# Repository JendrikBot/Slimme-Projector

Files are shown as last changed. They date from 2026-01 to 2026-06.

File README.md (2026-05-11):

# slimme lichtprojector
de slimme lichtprojector die kinderen ondersteunt bij het krijgen van een goede nachtrust.

🛠️ Built by Felix Vanhoutte & Jendrik Bottelberghe   
🔥 Supervised by prof. dr. Bas Baccarne& Yannick Christiaens. 
🌱 Grown at Ghent University 🏛️ Industrial Design Engineering ([project overview](https://github.com/basbaccarne/human-centered-design))       

11/05/2026 van de laatste update  

## Samenvatting
Slaapregressie bij jonge kinderen tussen 1,5 en 2,5 jaar vormt een terugkerend probleem voor gezinnen. Kinderen worden ’s nachts herhaaldelijk wakker en zoeken nabijheid en emotionele geruststelling, terwijl ouders te maken krijgen met slaaptekort, onzekerheid en een verhoogde mentale belasting. Bestaande oplossingen sluiten onvoldoende aan bij deze leeftijdsfase en vereisen vaak actieve ouderlijke tussenkomst of zorgen voor extra prikkels.

Het probleem werd onderzocht via gebruikersonderzoek en benchmarkanalyse. Er werden drie semigestructureerde interviews afgenomen met ouders en een grootouder die ervaring hebben met slaapregressie. De interviews focusten op nachtelijke patronen, emotionele impact en het gebruik van bestaande hulpmiddelen en werden geanalyseerd via thematische analyse. Daarnaast werd een benchmark uitgevoerd van tien bestaande producten en diensten rond slaapondersteuning bij jonge kinderen.

Op basis van deze inzichten werd een warm, slaapondersteunend systeem voorgesteld dat inspeelt op emotionele regulatie in plaats van gedragssturing. De oplossing maakt gebruik van subtiele zintuiglijke signalen zoals zacht licht, geluid en ritme, zonder schermen of actieve interactie.

Door automatisch en passief te werken, biedt het systeem het kind een gevoel van nabijheid en veiligheid, terwijl de nood aan nachtelijke ouderlijke tussenkomst vermindert. Zo creëert de oplossing rust voor zowel kind als ouder.

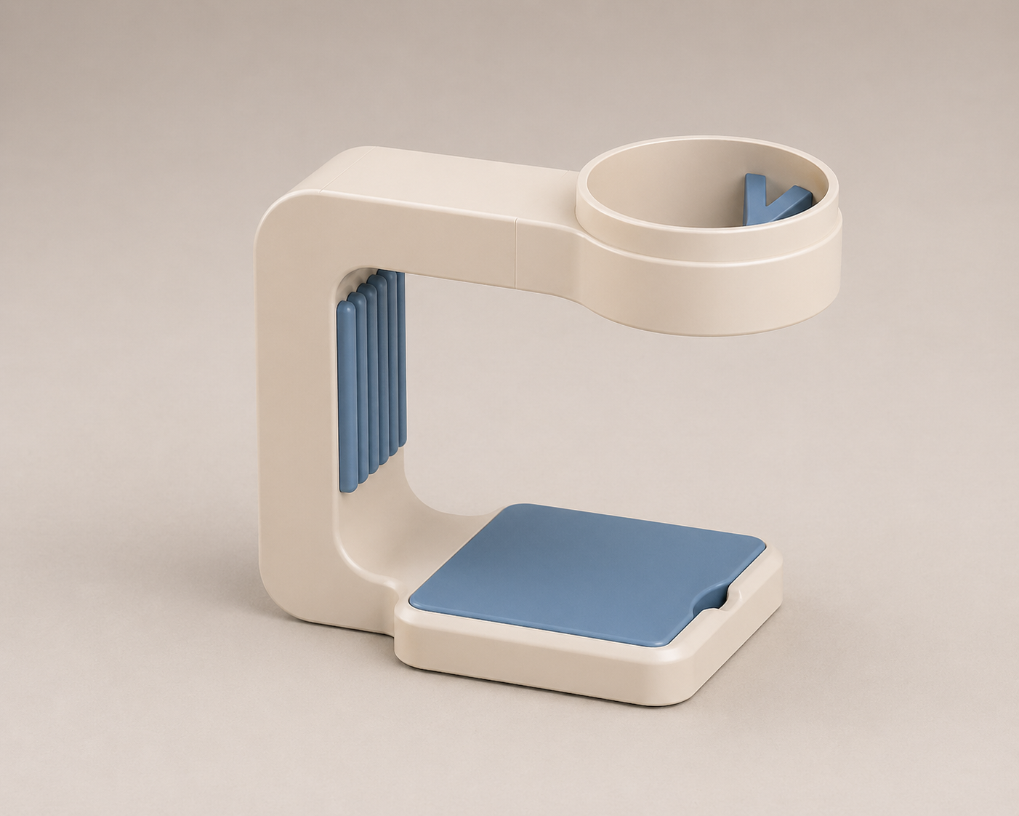
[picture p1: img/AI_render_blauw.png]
render


## Introductie
De slimme lichtprojector biedt hulp aan kinderen met slaapproblematiek. Het probleem dat ouders midden in de nacht wakker gemaakt worden door hun kinderen dient opgelost te worden met behulp van ons project. De slimme lichtprojector merkt op dat het kind ontwaakt en schiet meteen in actie. De projector schijnt rustgevende, ritmische beelden of strobes en maakt witte ruis om het kind rustiger te maken. De instellingen van de projector kunnen door de ouders ingesteld worden met behulp van een app. Zo kan het product op elk kind afgesteld worden. Het is de bedoeling dat de projector zo gemakkelijk mogelijk te installeren is, zonder veel kabels te moeten verbinden of gaten te moeten boren in het plafond. 

Maak gebruik van bronverwijzingen ([zie APA stijl](https://www.scribbr.nl/category/apa-stijl/)). Zoals bijvoorbeeld (Thomas & Ritter, 2022) [^1] .

## Inhoudstafel

1. [Methodologie](./docs/methodologie.md)
2. [Discovery](./docs/discovery.md)
3. [Definition](./docs/definition.md)
4. [Develop](./docs/develop.md)
5. [Design Requirements](./docs/design_requirements.md)
6. [Bill of materials](./docs/bom.md)

## Kritische reflectie

We hebben in deze fase van het ontwerpproces al verschillende waardevolle inzichten verkregen die richting geven aan belangrijke ontwerpkeuzes. Zowel uit de discovery-fase als uit de daaropvolgende gebruikerstesten werd duidelijk welke elementen essentieel zijn voor een effectief en rustgevend slaapondersteunend systeem. Zo bevestigden de interviews en benchmarkstudie dat slaapregressie bij jonge kinderen primair een probleem is van emotionele regulatie en nabijheidsbehoefte, en dat bestaande oplossingen onvoldoende aansluiten bij deze specifieke leeftijdsgroep. De gebruikerstesten met het ophangsysteem, de spreekfunctie en de energievoorziening brachten bovendien concrete frictiepunten aan het licht rond veiligheid, installatiegemak, voorspelbaarheid en betrouwbaarheid in een nachtelijke context.

Tegelijkertijd zijn er nog verschillende elementen waarin we ons verder willen verdiepen. Zo blijft de vraag open hoe het ophangsysteem even veilig en stabiel kan worden ontworpen zonder invasieve installatie zoals boren, en hoe dit op een intuïtieve manier kan worden gecommuniceerd naar ouders. Ook de automatische en passieve activatie van de spreekfunctie tijdens de nacht vraagt verdere uitwerking, zowel technisch als in termen van gebruikservaring en controle. Daarnaast is het nodig om de voorspelbaarheid van het systeemgedrag verder te versterken, zodat zowel kind als ouder vertrouwen kunnen opbouwen in de werking ervan. Deze open vragen vormen duidelijke ontwerpopportuniteiten voor de volgende iteraties.

We zijn tevreden over de manier waarop het onderzoek tot nu toe werd opgezet en uitgevoerd. De combinatie van semigestructureerde interviews, benchmarkanalyse en taakgebaseerde gebruikerstesten leverde rijke, relevante inzichten op die rechtstreeks konden worden vertaald naar design requirements en ontwerpimplicaties. Ook de keuze om te werken met low-fidelity prototypes en Figma-simulaties bleek effectief om vroegtijdig gebruikservaringen te testen zonder onnodige technische complexiteit.

Het teamwork had in deze fase beter kunnen verlopen. Er waren momenten waarop de afstemming en taakverdeling niet optimaal waren, wat soms leidde tot vertragingen of onduidelijkheden. Dit werd echter onderling besproken en geëvalueerd, en er zijn duidelijke afspraken gemaakt om de samenwerking in de volgende fases gestructureerder en efficiënter aan te pakken. Er wordt rekening gehouden met een betere planning, helderdere communicatie en een evenwichtige verdeling van verantwoordelijkheden. Hierdoor verwachten we dat ons team in de volgende ontwerpfases doelgerichter en coherenter kan werken aan de verdere ontwikkeling van het concept.

## Noot inzake het gebruik van AI
AI werd in dit project gebruikt om duiding te geven bij opdrachten, het helpen opstellen van de protocols met eigen bijsturing, en het herschrijven en grammatisch corrigeren van bepaalde stukken tekst. Artificiële intilligentie werd niet gebruikt als bron, echter biedde het wel hulp bij het uitleggen en sturen van onderzoek.

## Bijlagen
### Discovery

* Literatuuronderzoek (N=)
  * [Protocol](./reports%20and%20protocols/Bottelberghe_Jendrik_Protocol%20literatuuronderzoek%20JB.pdf)
  * [Rapport](./reports%20and%20protocols/Bottelberghe_Jendrik_rapportering%20literatuuronderzoek%20JB.pdf)
* Interviews (N=6)
  * [Protocol_1](./reports%20and%20protocols/Bottelberghe_Jendrik_Interview_protocol_PGGO_dokter%20JB.pdf)
  * [protocol_2](./reports%20and%20protocols/Bottelberghe_Jendrik_Interview_protocol_PGGO_ouders%20JB.pdf)
  * [Rapport](./reports%20and%20protocols/Bottelberghe_Jendrik_Rapportering%20interviews%20JB.pdf)

### Definition
* User testing wave 1 (N=8)
  * [Protocol](./reports%20and%20protocols/Bottelberghe_Jendrik_onderzoeksprotocol%20ophangsysteem.pdf)
  * [Rapport](./reports%20and%20protocols/Bottelberghe_Jendrik_rapportering%20TAP.pdf)
* User testing wave 2 (N=8)
  * [Protocol](url)
  * [Rapport](url)

* Literatuuronderzoek 
  * [Protocol](./reports%20and%20protocols/Bottelberghe_Jendrik_Protocol%20literatuuronderzoek%20JB.pdf)
  * [Rapport](./reports%20and%20protocols/Bottelberghe_Jendrik_rapportering%20literatuuronderzoek%20JB.pdf)
* Benchmarkonderzoek
  * [protocol](./reports%20and%20protocols/Benchmarkprotocol_slaapregressie%20Felix.pdf)
  * [rapport](./reports%20and%20protocols/Benchmark_uitvoering_slaapregressieFelix.pdf)
* Interviews (N=6)
  * [Protocol_Jendrik_1](./reports%20and%20protocols/Bottelberghe_Jendrik_Interview_protocol_PGGO_dokter%20JB.pdf)
  * [protocol_Jendrik_2](./reports%20and%20protocols/Bottelberghe_Jendrik_Interview_protocol_PGGO_ouders%20JB.pdf)
  * [protocol_Felix](./reports%20and%20protocols/Interview%20-%20protocol%20Felix.pdf)
  * [Rapport_Jendrik](./reports%20and%20protocols/Bottelberghe_Jendrik_Rapportering%20interviews%20JB.pdf)
  * [rapport_Felix](./reports%20and%20protocols/Interview%20report%20Felix.pdf)
### Definition
* User testing wave 1 (N=4)
  * [Protocol_Jendrik](./reports%20and%20protocols/Bottelberghe_Jendrik_onderzoeksprotocol%20ophangsysteem.pdf)
  * [Rapport_Jendrik](./reports%20and%20protocols/Bottelberghe_Jendrik_rapportering%20TAP.pdf)
* User testing wave 2 (N=4)
  * [Protocol_Felix](./reports%20and%20protocols/Onderzoeksprotocol%20spreekfunctie,%20energievoorziening%20(QAP).pdf)
  * [Rapport_Felix](./reports%20and%20protocols/FelixVanhoutteRapporteringQAP.pdf)

## Licentie

This repository contains both software and design materials created as part of an industrial design engineering project at Ghent University.

- **Software and code:** [MIT License](./LICENSE-MIT)  
- **Design, documentation, CAD, and media:** [CC BY 4.0 License](./LICENSE)
  
You are free to reuse and build upon this work, both commercially and non-commercially, as long as proper attribution is given to the original authors.

## Bronnen
Summer, J. V. (2025, 11 juli). What color light helps you sleep? Sleep Foundation. https://www.sleepfoundation.org/bedroom-environment/what-color-light-helps-you-sleep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,morning%2C%20known%20as%20sleep%20inertia

Sleep Foundation. (2025, 29 juli). Music and Sleep. https://www.sleepfoundation.org/noise-and-sleep/music

Loewy, J. L. (2013). The Effects of Music Therapy on Vital Signs, Feeding, and Sleep in Premature Infants (5de editie, Vol. 131). https://publications.aap.org/pediatrics/article-abstract/131/5/902/31313/The-Effects-of-Music-Therapy-on-Vital-Signs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

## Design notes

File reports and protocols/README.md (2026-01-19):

Add PDF versions of your protocols and reports here.   
   
- ❗Make sure this data is pseudonomized (give an alias to your respondent)    
- ❗Don't share personal information here.   
- ❗For informed consents and other documents that contain personal information: Add links to a OndeDrive folder and only give access to teachers.

## Reports

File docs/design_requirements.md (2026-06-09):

## Overzicht van Design Requirements

| ID | Beschrijving | Bron | Status |
|----|---|---|---|
| **1.1** | Het systeem moet emotionele geruststelling bieden aan kinderen via zachte, niet-stimulerende signalen (licht, geluid, ritme). | Discovery – Interviews, Thema 2 | ✅ voldaan |
| **1.2** | Het systeem mag geen overprikkeling veroorzaken (geen schermen, felle kleuren, harde geluiden of complexe interacties). | Discovery – Benchmark, Thema 4 | ✅ voldaan |
| **1.3** | Het systeem moet autonoom en passief kunnen functioneren tijdens de nacht, zonder actieve tussenkomst van ouders. | Discovery – Designimplicaties | ✅ voldaan |
| **1.4** | Het systeem moet voorspelbaar en consistent gedrag vertonen zodat kind en ouder conditionering en vertrouwen kunnen opbouwen. | Discovery – Thema 1 | ✅ voldaan |
| **2.1** | Het systeem moet altijd beschikbaar en betrouwbaar zijn gedurende de volledige nacht. | Definition – Energievoorzieningstest (QAP) | ✅ voldaan |
~~| **2.2** | De spreekfunctie moet onmiddellijk herkenbaar zijn als een geruststellende ouderstem en geen extra mentale belasting veroorzaken. | User test – QAP | ⚠️ gedeeltelijk voldaan |~~
| **2.3** | Het ophangsysteem moet veilig, stabiel en niet-storend zijn in de slaapkamercontext. | User test – Wave 2 | ✅ voldaan |
| **2.4** | De installatie van het systeem moet laagdrempelig en intuïtief zijn, met minimale invasiviteit (bijv. zonder boren). | User test – Think Aloud / Wave 2 | ✅ voldaan |
| **3.1** | Het systeem moet huilgeluiden van een kind kunnen detecteren op basis van een instelbare geluidsdrempel zodat vals alarm door achtergrondgeluid wordt vermeden. | Develop – Detectiedrempel (Decibel) | ✅ voldaan |
| **3.2** | Het systeem moet automatisch een rustgevende projectie activeren wanneer huilen wordt gedetecteerd zonder dat ouders moeten ingrijpen.  | Develop – User flow / Activatie | ✅ voldaan |
| **3.3** | Het systeem moet binnen enkele seconden reageren nadat een relevant huilgeluid is gedetecteerd. | Develop – Reactiesnelheid systeem | ✅ voldaan |
| **3.4** | Het systeem moet automatisch terugkeren naar monitoringmodus wanneer het huilen stopt. | Develop – User flow | ✅ voldaan |
| **3.5** | Het systeem moet binnen ≤ 3 seconden operationeel zijn na activatie. | Develop – User test | ✅ voldaan |
| **3.6** | De powerknop moet direct zichtbaar en herkenbaar zijn (visuele signifier). | Develop – User test | ❌ niet voldaan |
| **3.7** | Het geluidsniveau moet onder een storingsdrempel liggen voor nachtgebruik. | Develop – User test | ⚠️ gedeeltelijk voldaan |

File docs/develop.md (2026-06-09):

## Develop

## Develop 1

## Analyse en Prioritering

1. Onderzoeksvragen + hypotheses

1.1. Effectiviteit van het systeem

· Hoe effectief is het systeem in het detecteren en reageren op geluid?

· Het systeem reageert correct op relevante geluiden en vermindert het probleem waarvoor het ontworpen is.

1.2. Detectiedrempel (Decibel)

· Vanaf welk geluidsniveau moet het systeem reageren om vals alarm te vermijden?

· Een drempel boven het gemiddelde achtergrondgeluid zorgt ervoor dat het systeem enkel reageert op relevante geluiden. Later is het eventueel ook mogelijk om een algoritme te gebruiken dat kinder- en volwassengeluiden onderscheidt.

1.3. Integratie van een speaker

· Verhoogt een geïntegreerde speaker de effectiviteit van het systeem?

· Het rustegevende effect van geluid kan niet gegarandeerd worden en wordt dus niet verde meegenomen. verder zou een auditieve uitvoer voor een audio feedback loop kunnen zorgen.

1.4. Installatie / ophangen

· Is het haalbaar en praktisch om het systeem op te hangen?

· Het vermoeden is dat het systeem beter zal werken als het op een nachtkastje of op de grond zal staan. Ook is het dan makkelijker te installeren.

1.5. Reactiesnelheid van het systeem

· Hoe snel moet het systeem reageren nadat een relevant geluid is gedetecteerd?

· Het systeem moet binnen enkele seconden reageren na detectie van een relevant geluid om effectief te zijn en de gewenste reactie uit te lokken

## Deconstructie

**storyboard**

Om een duidelijker beeld te krijgen in de visie van de werking van het systeem werd een nieuwe iteratie van een storyboard gemaakt. Dit werd getekend, rekening houdend met de inzchten die verkregen werden tijdens de feedback. Na overleg van de priotering werd dit [storyboard](/img/afbeelding%20storyboard%20develop%201.JPEG) getekend.

**Productarchitectuur (I/O)**

Om vroegtijdig een beeld te krijgen van naarmate de technische ideeën mogelijk waren, werd een raspberry pi zero 2 W aangekocht samen met een draagbare projector. Toen de verbinding met behulp van code slaagde, was het duidelijk dat er op deze manier verder gebouwd kon worden. De verschillende sensoren, actuatoren en datastromen  zijn in een [productarchitectuur](/img/productarchitectuur_develop_1.png) in kaart gebracht.

**User flows & Informatiearchitectuur**

* User flow
Deze [user flow](/img/userflow_develop_1.jpg) is gebaseerd op de Hierarchical Task Analysis (HTA) met als hoofddoel “0. Het kind terug in slaap krijgen”. Wanneer het kind begint te huilen, detecteert de microfoon van het systeem het geluid en analyseert het of het effectief om huilen gaat. Indien dit het geval is, activeert het systeem automatisch de projector.

De projector projecteert rustgevende beelden op het plafond. Zodra het huilen stopt en het kind opnieuw rustig wordt, detecteert het systeem dit en dimt de projector geleidelijk. Daarna keert het systeem terug naar de monitoringmodus.

Deze flow toont hoe het systeem automatisch reageert op huilen en het kind helpt om opnieuw in slaap te vallen zonder tussenkomst van de ouders.

* Informatiearchitectuur

1. Information Ecology

Gebruikers:
· Ouders van kinderen die slaapregressie ervaren

· Vermoeide ouders die een snelle en eenvoudige interactie nodig hebben

· Het kind dat indirect met het systeem interageert

Inhoud:
· Detectie van huilen

· Gevoeligheid van de microfoon

· Projector aan/uit

· Type projectie

· Animatie

· Timer

· Automatische activatie

· Slaapstatus van het kind

· Meldingen naar ouders

· Instellingen

Context:
· Gebruik tijdens de nacht

· Ouders hebben weinig aandacht of energie om met het systeem te interageren

· Minimale interactie is gewenst

· Het product reageert automatisch wanneer het kind huilt

1. Card Sorting Methode

Voor het bepalen van de informatiearchitectuur werd een open card sorting methode gebruikt. Deelnemers kregen kaarten met verschillende functies van het systeem en werden gevraagd deze in logische groepen te verdelen. Daarna gaven zij elke groep een naam. Deze methode helpt om de mentale modellen van gebruikers te begrijpen.

| Informatie-item | Detectie | Projector | Geluid | Automatisch systeem | Instellingen |
|---|---|---|---|---|---|
| Microfoon detecteert huilen  | ✓ | | | | |
| Huilanalyse | ✓ | | | | |
| Projector starten | | ✓ | | | |
| Projectie kiezen | | ✓ | | | |
| Helderheid | | ✓ | | | |
| Rustgevende muziek | | | ✓ | | |
| Volume | | | ✓ | | |
| White noise | | | ✓ | | |
| Automatische activatie | | | | ✓ | |
| Timer | | | | ✓ | |
| Nachtmodus | | | | ✓ | |
| Microfoon gevoeligheid | | | | | ✓ |
| Meldingen naar ouders | | | | | ✓ |

 ## Diagram / Informatiearchitectuur

- **Slaapprojector Systeem**
  - **Detectie**
    - Huildetectie via microfoon
    - Geluidsanalyse
    - Slaapstatus kind
  - **Projectie**
    - Projector aan/uit
    - Type projectie
    - Animatie
    - Helderheid
  - **Geluid**
    - Rustgevende deuntjes
    - Muziekselectie
    - White noise
    - Volume
  - **Automatische reactie**
    - Activatie bij huilen
    - Timer
    - Nachtmodus
  - **Instellingen**
    - Microfoongevoeligheid
    - Meldingen naar ouders
    - Systeeminstellingen

**MVP-definitie**

In deze fase werd duidelijk dat de prioriteiten voor een deel anders liggen dan voordien. De focus van dit product lag in het begin van de fases vooral op het dilemma dat ging over het installatiesysteem (ophanging of neerzetten). In deze fase lag dit eerder achterwege. Nu de projector aangekocht is, kan meer gefocust worden op aspecten zoals activatie, geluid detectie en het beperken van mogelijke nadelen.
De minimal viabel productfuncties besluiten we op basis hiervan:

* Wake detection: activatie als drempelwaarde overschreden wordt.

* Activatie van systeem: Python programma draait automatisch na opstarten, zonder manuele interactie.

* Onderdrukking van bijkomende ruis:  Het bijkomend lawaai van de ingebouwde ventilatie in de projector is geen storende factor.

***Een systeem dat automatisch geluid detecteert bij een slapend kind en een rustgevende projectie toont om het kind weer tot rust te brengen.***

## Divergentie & Ontwerpkeuzes

* Morfologische Matrix:

| Functie / Probleem | Oplossing 1 | Oplossing 2 | Oplossing 3 | Oplossing 4 |
|---|---|---|---|---|
| Detectie van huilen / wakker zijn | Microfoon | Bewegingssensor | Combinatie geluid + beweging | |
| Activatie systeem | Automatisch bij huilen | Bij beweging van het kind | Handmatig via app | Constant aan |
| Visuele geruststelling | Sterrenprojectie | Dierenanimaties | Rustgevende kleuren | Bewegende wolken | |
| Intensiteit aanpassen | Vast niveau | Automatisch aanpassen | Manueel instellen via de app | Adaptief op basis van huilvolume |
| Stoppen van projectie | Timer | Wanneer huilen stopt | Ouder via app | Geleidelijke dimmen |
| Feedback naar ouders | Geen feedback | Meldingen via app | Geluidsmelding | Slaaprapport |

* Toelichting:

Om verschillende oplossingsmogelijkheden te verkennen werd een morfologische matrix opgesteld. Deze methode helpt om voor elke functionele uitdaging meerdere mogelijke oplossingen te genereren en te combineren. Hierdoor is het mogelijk om systematisch verschillende ontwerpvarianten te onderzoeken.

Voor het slaapprojector-concept werden onder andere oplossingen onderzocht voor de detectie van huilen, de activatie van het systeem, visuele geruststelling en het automatisch stoppen van het systeem. Door verschillende oplossingen uit de matrix te combineren kunnen meerdere conceptvarianten worden ontwikkeld.

## Build & Test

In deze fase van het ontwerp was het vooral belangrijk om een idee te krijgen in de moeilijkheidsgraad van de werking. Het voornaamste doel was om te kunnen bewijzen dat een audio-input een output kon geven via een projector, en dit is geslaagd. Nu het zeker is dat het mogelijk is om op de huidige componenten verder te bouwen, volgen meer user-tests en gebruikersonderzoeken. De [eerste iteratie](/img/afbeelding_samenstelling_1.JPEG) van de proof of concept bestond uit een custom 3D-print dat de boog van de projector volgt, beschikt met gaten om de raspberry pi module aan te bevestigen. Deze werd met plakband vastgemaakt om een oordeel te kunnen vellen over passing. De [tweede iteratie](/img/afbeelding_samenstelling_2.JPG) kwam na de conclusie dat de passing voldeed en bevestigt de componenten met klitteband.

## Develop 2

**Usability Goals**

Voor dit ontwerp is het voor de gebruiksvriendelijkheid het belangrijkst dat de projector makkelijk en intuïtief op te stellen is. Ook was het belangrijk dat de projector een mooie projectie had, ookal was het makkelijk om op te stellen. Als rode draad door het project speelde de veiligheid van het kind ook een primaire rol.

* De projector kan opgezet worden binnen 120 seconden.

* De projectie is scherp

* Het ontwerp is kindveilig

**Antropometrische analyse**

In dit project leek een Antropometrische analyse eerst weinig zin te hebben, aangezien het ontwerp niet zwaar was en geplaatst wordt op een nachtkast of dergelijke dat afhankelijk is van de gebruiker.
Waar in dit project wel rekening mee gehouden kan worden zijn de minimale en maximale afmetingen voor een scherp beeld. Er werd gezocht naar de kortste en verste afstand tussen projector en projectvlak waarbij het beeld scherp kon zijn en dit bracht volgende resultaten:

| | lengte (mm) | hoogte (mm) | afstand (mm) |
|---|---|---|---|
| min voc | 670 | 375 | 650 |
| max voc | 2050 | – | 1860 |

Uit deze resultaten blijkt dat er weinig tot geen rekening gehouden moet worden met deze parameters. Er kan geconcludeerd worden dat een stationaire projector (staand) zonder problemen gebruikt kan worden. 

**Cognitieve & sensoriële ergonomie**

Na Develop 1 werd een [nieuw prototype]() ontworpen. Hoewel dit een stap in de goede richting was, was dit niet volledig geschikt om mee verder te gaan. Het model was te groot en te omvangrijk om esthetische waarde te hebben. Na vorig ontwerp werd een [tweede iteratie](/img/develop_2_prototype.JPEG) ontworpen, dit keer werd besloten om de kabels minder te verstoppen en verder te werken op de support. Met dit prototype werd een praktijktest uitgevoerd om tekortkomingen na te gaan bij gebruikers. Hoewel het project systemisch wel slaagde, waren er 2 grote werkpunten. Zo was de opstarttijd te lang waardoor de *Gulf of Execution* vergroot, aangezien het ontwakingsmoment niet meteen kan opgevangen worden door een reactie. Het tweede grote werkpunt was het storende geluid van de projector. Uit deze frustraties en de andere interacties die uit de gebruikerstest voortkwamen werd een [7 stages of action](/img/seven_stages_of_action.png) opgesteld. Daaruit bleek ook dat een duidelijke signifier voor de power button handig kan zijn om de *Gulf of execution* te verkleinen. 

## Develop 3

**stap 1 : UX & Service Design Challenges**
*Emotioneel Ontwerp:*
In de eerste fase van Develop 3 werd eerst de eerste indruk onderzocht en wat we daar bereikt moest worden om een zo goed mogelijke user experience te bekomen. Dit wordt bepaald door: 
* Vorm
* Kleur
* Lichtintensiteit
* Geluid
* Materiaal

Dit werd allemaal onderzocht en uitgewerkt in [dit UX onderzoeksrapport](/reports%20and%20protocols/UX_Felix%20Vanhoutte%20.pdf). 
Om dit rapport samen te vatten stellen we dat een ronde vorm de voorkeur had tegenover scherpere vormen, dat zachte kleuren zoals blauw, beige en pastel, de mentale belasting verminderen en dat te felle kleuren of contrasten zouden botsen met het doel dat vooropgesteld was. Verder bleek het ook dat het nodig was om  warme materialen (textiel, silicone) te gebruiken omdat deze menselijk en betrouwbaarder aanvoelen. 

*Service Design:* 
Om een compleet beeld te schetsen van de baan die een gebruiker aflegt met het ontwerp, werd een customer journey opgesteld. Deze werd in drie fases opgedeeld, namelijk: 
* Fase 1 : voor het gebruik
In deze fase merken ouders dat hun kind het lastig heeft met volledige nachten door te slapen. Misschien doen ze hier onderzoek, vragen ze advies of maken ze gebruik van andere bestaande producten.
* Fase 2 : tijdens het gebruik
In plaats van de ouders die tussenkomen bij de verstoorde nachtrust van het kind, detecteert het product geluidssignalen en biedt het ondersteuning. Door het ontwerp van het product ervaren de ouders zo weinig mogelijk cognitieve belasting. Het product heeft echter slechts een bufferwerking en neemt dus niet de ouderrol over.
* Fase 3 : Na het gebruik
Na het gebruik valt het kind terug in slaap of verbeteren op langere termijn de routines van het kind. Ouders ervaren een daling in hun stress door minder verstoorde nachten.

Verder werd in deze stap nog een stakeholder mapping en service blueprint gemaakt, dat terug te vinden is in [de rapportering](/reports%20and%20protocols/service_design_Felix%20Vanhoutte.pdf).

**stap 2 :CMF-analyse** 
Als eerst werd er voor de CMF-analyse gekeken naar de inbreng van de gebruikers en de directe stakeholders. Via de gegeven woordenlijst op Ufora werden voor 4 categoriën verschillende productomschrijvingen aangewezen. 
| Categorie | Kenmerk 1 | Kenmerk 2 | Kenmerk 3 | Kenmerk 4 |
|---|---|---|---|---|
| **vorm** | minimalistisch | afgerond | harmonieus | organisch |
| **materiaal** | lichtgewicht | mat | solide | verfijnd  |
| **gebruik** | functioneel | intuïtief  | toegankelijk | compact |
| **emotie** | speels | neutraal | elegant | |

Hierna werden patronen gezocht uit referentie-producten die gekozen werden. Deze producten zijn geen benchmarks, maar staven enkel de uitstraling en UX die met dit product nagestreefd worden. Uiteindelijk werden [deze foto's](/img/referentiefoto's.pdf) uitgekozen. Deze werden in Claude (Anthropic) geanalyseerd en er werd gevraagd om patronen te zoeken tussen de referentiefoto's om een CMF-strategie op te stellen. 
# Patronen
- organisch
- mat
- afgerond
- tastcontrast
- warm
- verfijnd
- kalm 

Hierna werden de patronen en de productomschrijvingen vergeleken en werden onderstaande keuzes gemaakt. 
| Nr | C1 (basiskleur) | C2 (accentkleur) | M (materialen) | F1 (visuele afwerking) | F2 (tactiele afwerking) |
|----|---|---|---|---|---|
| 1 | zwart | **blauw**| **PLA (stijf, standaard)** | **mat** | micro-textuur |
| 2 | donkergrijs | rood | **TPU (flexibel, grip)** | hoogglans | **soft-touch** |
| 3 | lichtgrijs | geel | PETG (semi-transparant, slagvast) | geborsteld | **glad** |
| 4 | wit | groen | PVA (oplosbaar, niche) | transparant | ruw |
| 5 | **crème** |  | ABS (impact, industriëler) | satijn | rubberized |
| 6 |  |  | PC (polycarbonaat, high-end, transparant mogelijk) | translucent | geknurlt |
| 7 |  |  | PP (licht, flexibel scharnierend) |  | geribbeld |
| 8 |  |  | aluminium (metaal, premium referentie) |  |  |
| 9 |  |  | nylon (PA, slijtvast) |  |  |

Op basis van deze keuzes en de huidige visie van hoe het ontwerp er moet komen uit te zien, werd met Vizcom een [render](/img/render_Vizcom.png) gegenereerd. Aangezien de vorm van deze render goed gepaard ging met de voorafgaande keuzes, werd op basis hiervan een [eigen iteratie](/img/model_NX_JB.png) gemodelleerd in Siemens NX en werd hierop de CMF-strategie toegepast met behulp van ChatGPT om een [nieuwe render](/img/AI_render_blauw.png) te verkrijgen. Deze werd nog eens in [andere kleuren](/img/AI_render_multicolor.png) ook gegenereerd om toch nog eens extra te kunnen vergelijken.

**Stap 3 : Prototypevarianten & finale user test**

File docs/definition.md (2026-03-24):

## Definition

### Doestellingen
In deze fase van het ontwerp was het noodzakelijk om grote, belangrijke keuzes te maken om dan later met een goede basis verder te kunnen werken. Het product moet makkelijk op te zetten zijn en moet ook effectief rust bieden aan kinderen. De voornaamste onderzoeksvragen waren hierbij: "Hoe zal het product opgezet worden, zodat het functioneel is en niet in de weg hangt?" en " Kan een subtiele beweging in het ontwerp voor meer rust bieden of eerder onrust?"
Om op de eerste onderzoeksvraag te antwoorden werd een prototype in een eerste gebruikerstest volgens het "Think aloud program" getest. Met een ander prototype werd de tweede onderzoeksvraag getest. 
De testen werden uitgevoerd door ouders, aangezien zij het meest in contact zullen komen met het ontwerp.
### Materiaal & methoden

Tijdens de definitiefase werd sterk ingezet op [human-product interaction](/img/HPI.jpg), met als doel een oplossing te ontwikkelen die intuïtief, rustgevend en gebruiksvriendelijk is voor zowel kind als ouder. We kozen bewust voor een ontwerp zonder schermen en met een minimum aan knoppen, om de cognitieve belasting zo laag mogelijk te houden en het gebruik ’s nachts niet complex of storend te maken.

Daarnaast werd aandacht besteed aan een eenvoudige installatie, zonder boren of ingewikkelde instellingen, zodat de fysieke en mentale inspanning voor de gebruiker beperkt blijft. De interactie met het product gebeurt voornamelijk via zintuiglijke feedback, zoals licht en geluid, waardoor de gebruiker op een natuurlijke manier aanvoelt wat het systeem doet, zonder expliciete instructies nodig te hebben.

Tot slot werd ook de emotionele interactie meegenomen in het ontwerp. Het systeem is gericht op het creëren van een gevoel van rust en veiligheid, wat bijdraagt aan een positieve gebruikerservaring en het emotioneel comfort van het kind tijdens de nacht. Op deze manier wordt niet alleen de functionaliteit, maar ook de beleving van het product centraal gesteld.

Beide onderzoeken werden apart in twee waves uitgevoerd. 
Het eerste onderzoek maakte gebruik van een bureaulamp-armatuur, verbonden aan een 3D-geprinte vlinder dat de projector voorstelt. Deze werden verbonden met een touwtje. Ook was er een [figma template](https://www.figma.com/make/z6YTW5lYvv8C9mwTjm8RgK/Bluetooth-Projector-Control-Interface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), gegenereerd door Ai, die zich voordeed als de software van de lichtprojector. De eerste test volgde dit [protocol](../reports%20and%20protocols/onderzoeksprotocol%20ophangsysteem.pdf). Hier was de bedoeling dat de gebruiker enkele testjes volgde met het ontwerp en luidop vertelde wat ze aan het doen waren. Zo kon onderzocht worden als het ontwerp intuïtief genoeg was, en wat de gebruikers denken van het design. 

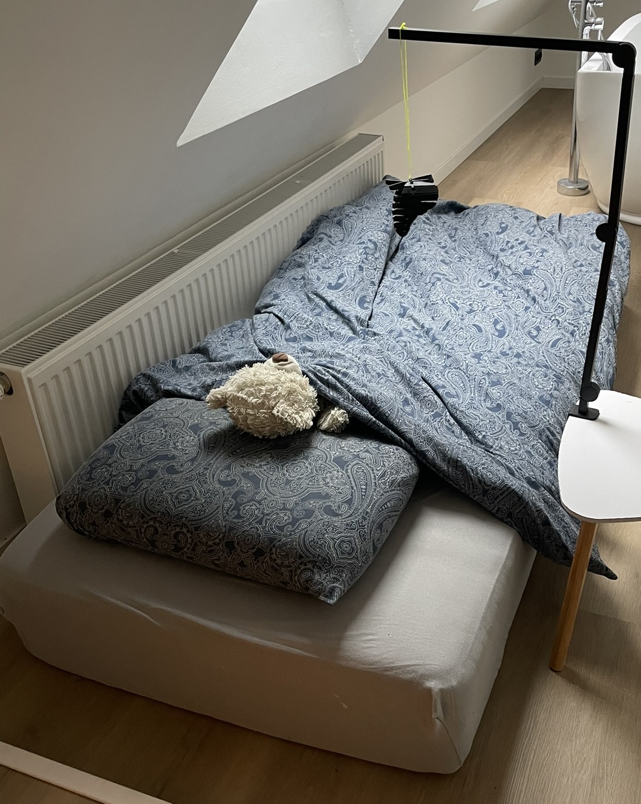
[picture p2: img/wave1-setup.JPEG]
eerste ontwerp

De resultaten van het eerste ontwerp maakten duidelijk dat er aanpassingen nodig waren. De feedback van de figma template was verrassend goed, hier werden ook geen verdere aanpassingen aan gedaan. Bij de tweede iteratie werd het ophangsysteem vereenvoudigd. De projector werd opgehangen boven het bed. Dit gebeurde met touwtjes die de projector vanaf het plafond naar beneden liet hangen.
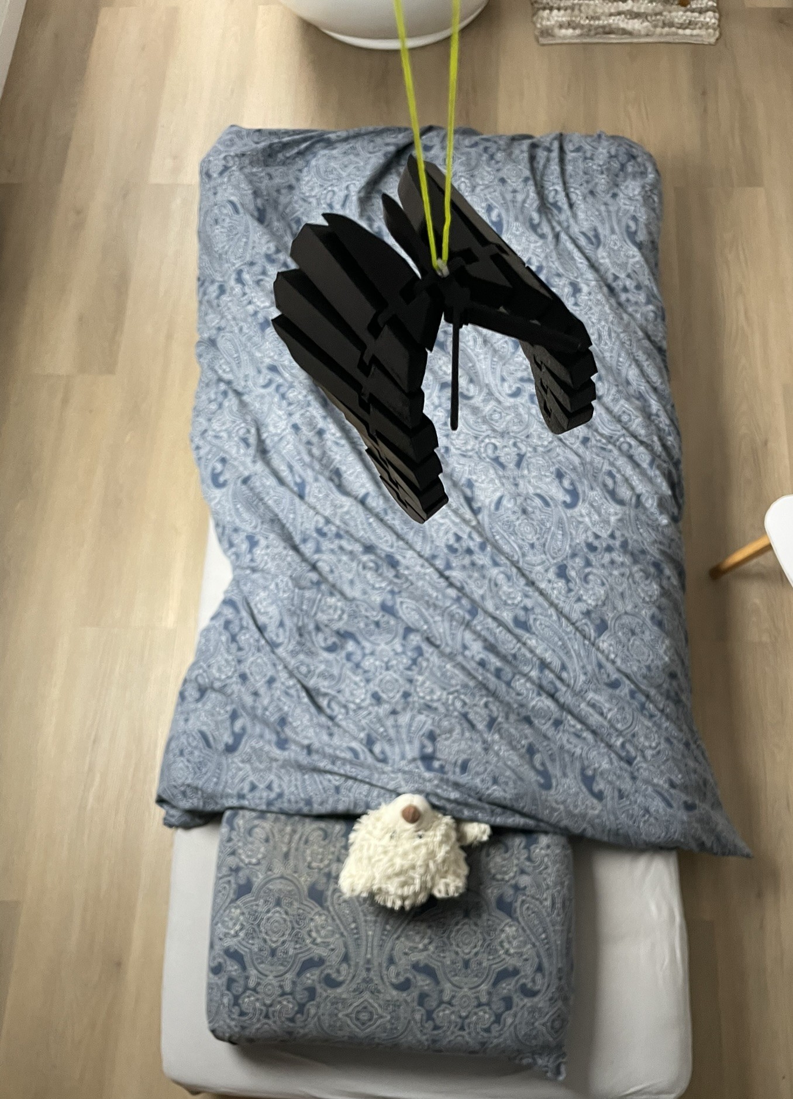
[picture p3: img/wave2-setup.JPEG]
tweede ontwerp

De gebruikers hadden meteen door hoe ze dit konden bevestigen. Het enige nadeel bij dit systeem was dat voor een hi-fi prototype er aanpassingen zullen moeten gebeuren aan het plafond (gaten boren / vijzen). Wanneer dit aan de gebruikers werd voorgelegd was dit een minder groot probleem dan gedacht. Aangezien deze manier een pak veiliger was dan dat in wave 1, was dit een goede verbetering.  

### Resultaten
Uit de gebruikservaring van de twee waves werd duidelijk dat het ophangsysteem in de tweede wave een upgrade was van de eerste versie. Dit was echter vooral omdat dit ontwerp veel veiliger was, en niet per se makkelijker op te zetten.
"Da geeft niet dat dat daar hangt te bengelen."
Ook kon het ontwerp niet in de weg staan. Er bleek echter wel noodzaak om de ophanging makkelijker te maken en eventueel zonder boren. Hoewel dit niet opwoog tegen veiligheid, waren er wel opmerkingen dat hier nog over nagedacht mocht worden. De UI van de software was goed. Alleen was er een idee van een gebruiker om custom voorgesproken stemfragmenten op te slaan. 
"Da's wel gemakkelijk, die app."

### Doestellingen

In deze fase van het ontwerp was het noodzakelijk om grote, belangrijke keuzes te maken om dan later met een goede basis verder te kunnen werken. Het product moet makkelijk op te zetten zijn en moet ook effectief rust bieden aan kinderen. De voornaamste onderzoeksvragen waren hierbij: "Hoe zal het product opgezet worden, zodat het functioneel is en niet in de weg hangt?" en "Hoe interpreteren en gebruiken ouders de spreekfunctie en welke energievoorziening heeft hun het meeste vertrouwen."
Om op de eerste onderzoeksvraag te antwoorden werd een prototype in een eerste gebruikerstest volgens het "Think aloud program" getest. Met een ander prototype werd de tweede onderzoeksvraag getest volgens "Questions Ask Protocol".
De testen werden uitgevoer door ouders, aangezien zij het meest in contact zullen komen met het ontwerp.

### Materiaal & methoden

Beide onderzoeken werden apart uitgevoerd.
Het eerste onderzoek maakte gebruik van een bureaulamp-armatuur, verbonden aan een 3D-geprinte vlinder dat de projector voorstelt. Deze werden verbonden met een touwtje. Ook was er een figma template, gegenereerd door Ai, die zich voordeed als de software van de lichtprojector.
[figma](https://www.figma.com/make/z6YTW5lYvv8C9mwTjm8RgK/Bluetooth-Projector-Control-Interface?t=xq9Ykq11bSMpZqXp-1).
De eerste test volgde dit [protocol](../reports%20and%20protocols/Bottelberghe_Jendrik_onderzoeksprotocol%20ophangsysteem.pdf). Hier was de bedoeling dat de gebruiker enkele testjes volgde met het ontwerp en luidop vertelde wat ze aan het doen waren. Zo kon onderzocht worden als het ontwerp intuïtief genoeg was, en wat de gebruiker denkt van het design.
eerste ontwerp
De resultaten van het eerste ontwerp maakten duidelijk dat er aanpassingen nodig waren. De feedback van de figma template was verrassend goed, hier werden ook geen verdere aanpassingen aan gedaan. Bij de tweede iteratie werd het ophangsysteem vereenvoudigd. De projector werd opgehangen boven het bed. Dit gebeurde met touwtjes die de projector vanaf het plafond naar beneden liet hangen.
tweede ontwerp
De gebruikers hadden meteen door hoe ze dit konden bevestigen. Het enige nadeel bij dit systeem was dat voor een hi-fi prototype er aanpassingen zullen moeten gebeuren aan het plafond (gaten boren / vijzen). Wanneer dit aan de gebruikers werd voorgelegd was dit een minder groot probleem dan gedacht. Aangezien deze manier een pak veiliger was dan dat in wave 1, was dit een goede verbetering.  

Het tweede onderzoek maakte gebruik van een low-fidelity fysiek prototype dat de projector voorstelde, met een ingebouwde speaker om de spreekfunctie te simuleren. Het prototype werd boven het kinderbed opgehangen om de gebruikscontext zo realistisch mogelijk te maken. Daarnaast werd een Figma-template, ontwikkeld om de bijhorende app na te bootsen waarmee ouders een boodschap konden inspreken en activeren.
De test werd uitgevoerd als een taak-gebaseerde gebruikstest met QAP volgens dit [protocol](../reports%20and%20protocols/Onderzoeksprotocol%20spreekfunctie,%20energievoorziening%20(QAP).pdf). Deelnemers gebruikten het systeem in verschillende scenario’s en verwoordden luidop wat ze deden en verwachtten. Zo werd onderzocht of de spreekfunctie intuïtief werd begrepen en hoeveel mentale belasting het gebruik van de app vroeg, gekoppeld aan de design requirements rond eenvoud, controle en lage cognitieve last.
 werkte het prototype op een oplaadbare batterij.
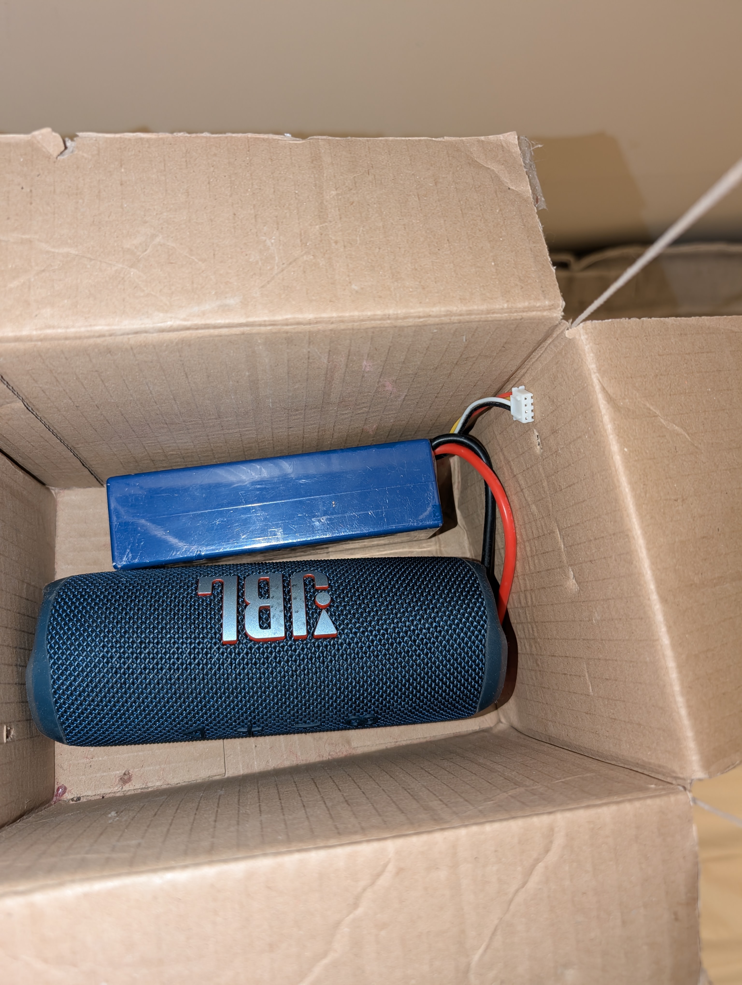
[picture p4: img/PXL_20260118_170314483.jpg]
eerste iteratie

in een tweede iteratie werd hetzelfde prototype getest met een vaste elektriciteitskabel.
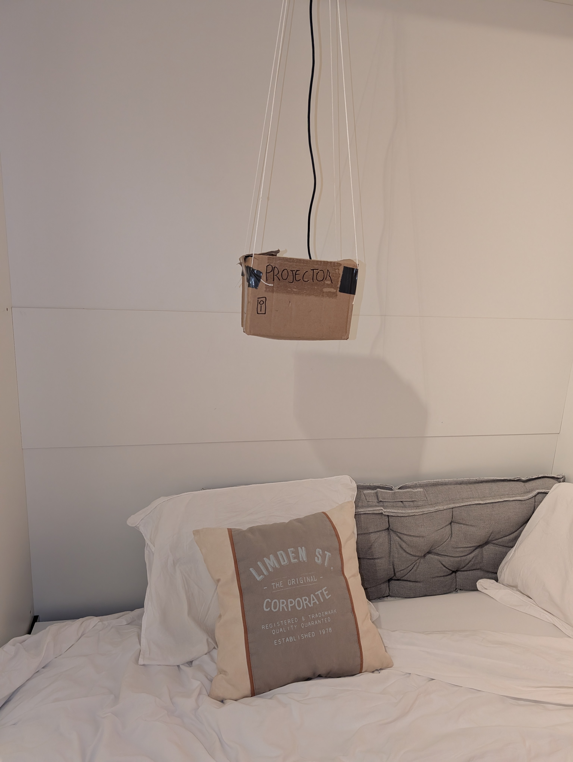
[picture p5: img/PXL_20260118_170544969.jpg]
tweede iteratie


### Resultaten

Uit de gebruikservaring van de twee waves werd duidelijk dat het ophangsysteem in de tweede wave een upgrade was van de eerste versie. Dit was echter vooral omdat dit ontwerp veel veiliger was, en niet per se makkelijker op te zetten.
"Da geeft niet dat dat daar hangt te bengelen."
Ook kon het ontwerp niet in de weg staan. Er bleek echter wel noodzaak om de ophanging makkelijker te maken en eventueel zonder boren. Hoewel dit niet opwoog tegen veiigheid, waren er wel opmerkingen dat hier nog over nagedacht mocht worden. De UI van de software was goed. Alleen was er een idee van een gebruiker om een instelbare tijd toe te voegen.
"Da's wel gemakkelijk, die app."

Uit de tweede test volgde:
De resultaten tonen aan dat de spreekfunctie snel en intuïtief werd begrepen: gebruikers herkenden meteen dat de ouderstem bedoeld was om het kind gerust te stellen bij nachtelijk ontwaken. Tegelijk gaf het QAP aan dat ouders twijfelden over het juiste moment en de frequentie van gebruik, wat wijst op een sterke behoefte aan controle en voorspelbaarheid. Wat betreft de energievoorziening bleek betrouwbaarheid belangrijker dan esthetiek. De batterijoplossing riep onzekerheid op over een mogelijk lege batterij tijdens de nacht en werd daardoor als risicovol ervaren. De vaste elektriciteitskabel gaf gebruikers meer rust en vertrouwen, ondanks het minder verzorgd uitzicht. Deze inzichten bevestigen dat het systeem altijd beschikbaar moet zijn zonder extra handelingen van de ouder, en dat ontwerpkeuzes in een nachtelijke context vooral moeten inzetten op zekerheid en mentale rust.

### Conclusies & implicaties

1. Keuze voor het vereenvoudigde ophangsysteem boven het bed:
Op basis van de gebruikerstesten werd beslist om het ophangsysteem uit wave 1 te verlaten en te kiezen voor het vereenvoudigde systeem waarbij de projector boven het kinderbed hangt, bevestigd aan het plafond met touwtjes.
Deze keuze werd niet gemaakt omdat het systeem per se makkelijker op te zetten was, maar omdat het als aanzienlijk veiliger werd ervaren en minder in de weg hing.
Hoewel gebruikers aangaven dat boren in het plafond niet ideaal is, woog dit nadeel niet op tegen de verhoogde veiligheid en stabiliteit.
Wel werd beslist dat in verdere iteraties gezocht moet worden naar een oplossing die even veilig is, maar minder invasief (bijvoorbeeld zonder boren).

2. Implementatie van de spreekfunctie met ouderstem:
De spreekfunctie werd behouden als kernfunctionaliteit van het product.
Uit de QAP-test bleek dat ouders deze functie onmiddellijk correct interpreteerden als een manier om hun kind te geruststellen bij nachtelijk ontwaken.
Daarmee werd bevestigd dat het concept begrijpelijk en emotioneel relevant is, zonder extra uitleg nodig te hebben.
Wel werd beslist dat het systeem duidelijke feedback moet geven over wanneer en hoe vaak de spreekfunctie actief is, om twijfel en mentale belasting te verminderen.

3. Keuze voor vaste elektriciteitskabel in plaats van batterij:
Op basis van de tweede gebruikerstest werd beslist om de oplaadbare batterij niet te gebruiken als primaire energievoorziening.
Gebruikers ervaarden onzekerheid over een lege batterij tijdens de nacht als een groot risico.
De vaste elektriciteitskabel werd verkozen omdat die meer betrouwbaarheid, rust en vertrouwen bood, ondanks het minder esthetische uitzicht.
Deze beslissing vertrekt expliciet vanuit de nachtelijke gebruikscontext, waarin zekerheid belangrijker is dan visuele afwerking.

4. Ontwerpprincipe: altijd beschikbaar, zonder extra handelingen
Overkoepelend werd beslist dat het systeem zo ontworpen moet worden dat het altijd operationeel is, zonder dat ouders vooraf iets moeten opladen, activeren of controleren.
Dit vertaalt zich in:

-een vaste stroomvoorziening

-automatische werking

-minimale instellingen

-duidelijke voorspelbaarheid van functies (zoals de spreekfunctie en timing)

Dit principe stuurt verdere ontwerpkeuzes aan, zowel hardwarematig als softwarematig.

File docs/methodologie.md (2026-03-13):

## Methodologie

Het ontwerpproces van dit project volgde een iteratieve, gebruiksgerichte aanpak, gebaseerd op een aangepast [Double Diamond-model](/img/Double_Diamond.jpg). Dit model structureert het proces in vier fasen: Discover, Define, Develop en Deliver. Doorheen alle fasen stond continue terugkoppeling via gebruikersonderzoek en testen centraal, met als doel het ontwerp af te stemmen op de noden van zowel kinderen als ouders.

De discoveryfase had als doel de probleemruimte rond slaapregressie bij jonge kinderen (1,5–2,5 jaar) in kaart te brengen. De focus lag op het begrijpen van emotionele, contextuele en praktische noden, en op het identificeren van ontwerpopportuniteiten voor een ondersteunend systeem dat nachtelijke onrust vermindert zonder voortdurende ouderlijke tussenkomst.

Hiervoor werden semigestructureerde interviews afgenomen met ouders en een grootouder (N=3). De interviews focusten op slaapregressiepatronen, nachtelijke routines, emotionele impact en ervaringen met bestaande hulpmiddelen. De data werden geanalyseerd via thematische analyse. Daarnaast werd een benchmarkonderzoek uitgevoerd van tien bestaande slaapondersteunende producten en diensten. Deze werden geëvalueerd op gebruiksgemak, zintuiglijke belasting, ouderafhankelijkheid en autonomie van het kind.

Uit deze fase bleek dat slaapregressie primair een probleem is van emotionele regulatie, met een grote impact op ouders en gezinsdynamiek. Bestaande oplossingen bleken gefragmenteerd, vaak te technisch of overprikkelend. Dit leidde tot de centrale How Might We-vraag:
Hoe kunnen we een warme, niet-invasieve technologie ontwerpen die jonge kinderen geruststelt tijdens slaapregressie en tegelijk de nachtelijke belasting voor ouders vermindert?

In de definitionfase werd de probleemstelling vertaald naar concrete ontwerpkeuzes. De belangrijkste doelstellingen waren veiligheid, eenvoud, intuïtief gebruik en het bevorderen van rust. Twee iteratieve testwaves werden uitgevoerd met ouders als gebruikers.

In wave 1 werd een exploratief prototype getest via een think-aloud-methode, bestaande uit een eenvoudig ophangsysteem en een Figma-interface die de software simuleerde. De test evalueerde intuïtiviteit, veiligheid en eerste indrukken. Op basis van de feedback werd het ontwerp aangepast.

In wave 2 werd een vereenvoudigd ophangsysteem getest waarbij de projector boven het bed werd bevestigd. Dit ontwerp werd als veiliger en duidelijker ervaren. De software-interface werd positief beoordeeld, met als enige optimalisatievoorstel het toevoegen van een instelbare timer.

Deze fase resulteerde in duidelijke ontwerpvereisten en een solide basis voor verdere ontwikkeling.

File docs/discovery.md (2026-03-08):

## Discovery

### Doestellingen
Het doel van deze discovery-fase was het in kaart brengen van de probleemruimte rond slaapregressie bij jonge kinderen tussen 1,5 en 2,5 jaar. De focus lag op het begrijpen van de emotionele, contextuele en praktische noden van ouders en kinderen, en het identificeren van ontwerpopportuniteiten voor een ondersteunend product dat nachtelijke onrust kan verminderen zonder de ouders voortdurend te belasten.
Deelvragen

· Welke momenten en patronen kenmerken slaapregressie bij kinderen van 1,5–2,5 jaar?

· Welke onderliggende oorzaken ervaren ouders als doorslaggevend?

· Welke impact heeft slaapregressie op ouders en het gezin?

· Welke bestaande producten en diensten ondersteunen slaap bij jonge kinderen, en waar schieten ze tekort?

· Welke ontwerpprincipes zijn essentieel voor een effectieve en warme slaapondersteuning?
### Materiaal & methoden
* Gebruikersonderzoek 
* Interviews

Er werden drie semigestructureerde interviews afgenomen met ouders en een grootouder die ervaring hebben met slaapregressie bij jonge kinderen (N=3). De respondenten werden doelgericht geselecteerd om variatie in gezinssituatie en ervaring te bekomen. De interviews duurden gemiddeld 45 minuten en werden opgenomen met toestemming van de respondenten.

De interviewgids focuste op:

· Ervaringen met slaapregressie

· Nachtelijke routines en probleemmomenten

· Emotionele impact op ouder en kind

· Gebruik en perceptie van bestaande hulpmiddelen

De data werden geanalyseerd via thematische analyse (open en axiaal coderen). Het interviewprotocol is opgenomen als bijlage.

Markt- en technologieonderzoek – Benchmark

Daarnaast werd een benchmarkonderzoek uitgevoerd van tien bestaande producten en diensten rond slaapondersteuning bij jonge kinderen (o.a. slaaptrainers, apps, monitoringtoestellen en troostobjecten). De selectie gebeurde op basis van relevantie voor peuterslaap en beschikbaarheid van documentatie.

De oplossingen werden geëvalueerd aan de hand van vaste criteria:

· Gebruiksgemak

· Mate van ouderafhankelijkheid

· Zintuiglijke belasting

· Leeftijdsspecificiteit

· App- en schermafhankelijkheid

· Autonomie van het kind

### Resultaten
Thema 1 : Slaapregressie als terugkerend patroon

Alle respondenten beschrijven slaapregressie als een voorspelbaar en herhalend fenomeen. Kinderen worden vaak op een vast tijdstip wakker, meestal na het eerste slaapblok. Ouders ervaren dit niet als een tijdelijke verstoring, maar als een structureel patroon dat hun nachtritme langdurig verstoort.

Analyse: Dit wijst op conditionering en vaste triggers, wat kansen biedt voor anticiperend en preventief ontwerp.

Thema 2 : Emotionele regulatie als kernprobleem

De oorzaak van slaapregressie wordt door alle respondenten gelinkt aan emotionele factoren zoals verlatingsangst, behoefte aan nabijheid en overprikkeling. Fysieke noden (honger, pijn) spelen volgens hen een ondergeschikte rol.

“Hij zoekt letterlijk nabijheid en geruststelling.”

Analyse: Slaapregressie vraagt geen actieve interactie, maar ondersteuning bij emotionele regulatie. Oplossingen moeten geborgenheid en rust uitstralen, niet stimuleren of activeren.

Thema 3 : Impact op ouders en gezinsdynamiek

De interviews tonen een sterke emotionele en fysieke belasting bij ouders: vermoeidheid, onzekerheid en spanningen binnen het gezin. Ouders zoeken oplossingen die hun kind helpen zonder dat zij telkens wakker moeten worden of ingrijpen.

Gevolg:         Observatie:

Slaaptekort     Verminderde energie en geduld

Onzekerheid     Geen duidelijke “handleiding”

Schuldgevoel    Twijfel over juiste aanpak

Analyse: De gebruiker is niet alleen het kind, maar ook de ouder. Ontwerp moet dubbele rust creëren.

Thema 4 : Beperkingen van bestaande oplossingen (Benchmark)

Het benchmarkonderzoek toont aan dat bestaande oplossingen sterk gefragmenteerd zijn.

Type oplossing:         Belangrijkste tekortkoming:

Monitoring & wearables  Te technisch en oudergericht

Slaaptrainers           Te cognitief voor deze leeftijd

Apps                    Scherm- en app-afhankelijk

Troostobjecten          Passief en niet adaptief

Analyse: Er ontbreekt een geïntegreerde oplossing die emotionele geruststelling biedt zonder overprikkeling of continue ouderlijke tussenkomst. 

### Conclusies & implicaties
Belangrijkste inzichten:

· Slaapregressie bij 1,5–2,5 jaar is primair een probleem van emotionele regulatie.

· Ouders zoeken ondersteuning, geen controleverlies of data-overload.

· Huidige producten zijn onvoldoende afgestemd op deze specifieke leeftijdsgroep.

· Overprikkeling werkt averechts; eenvoud en voorspelbaarheid zijn cruciaal.

· Zowel kind als ouder moeten ondersteund worden.

Designimplicaties

Deze inzichten leiden tot volgende kernbeslissingen:

Inzicht Designimplicatie

Emotionele nood Focus op geruststellende signalen

Inzicht:                         Designimplicatie:

Overprikkeling vermijden        Geen schermen, zachte stimuli

Nachtelijke autonomie           Automatische, passieve activatie

Ouderbetrokkenheid beperken     Transparante en instelbare werking

Integratie in routine           Onderdeel van avond- en nachtritueel

Ontwerpopportuniteit:

Er ligt een duidelijke opportuniteit voor een warm, phygital slaapondersteunend systeem dat subtiele zintuiglijke signalen inzet (licht, geluid, ritme) om nabijheid te simuleren en emotionele onrust te dempen, zonder de ouders actief te betrekken of het kind te overprikkelen.

* How Might We

Hoe kunnen we een warme, niet-invasieve technologie ontwerpen die jonge kinderen tijdens slaapregressie geruststelt en tegelijk de nachtelijke belasting voor ouders vermindert?

* 1) Minimale cognitieve en zintuiglijke belasting:

Het systeem mag geen schermen, felle kleuren, harde geluiden of complexe interacties bevatten.
Alle output moet zacht, traag en subtiel zijn (bijv. gedimd licht, rustige stem, repetitieve ritmes).
De interface voor ouders moet eenvoudig, intuïtief en laagdrempelig zijn, met een beperkt aantal instellingen en duidelijke feedback.

Afgeleid uit:
– Overprikkeling vermijden
– Eenvoud en voorspelbaarheid zijn cruciaal
– Beperkingen van bestaande apps en slaaptrainers

* 2) Automatische en passieve activatie tijdens de nacht:

Het systeem moet autonoom kunnen functioneren zonder actieve tussenkomst van ouders tijdens de nacht.
Activatie moet automatisch gebeuren op basis van vooraf ingestelde parameters (tijd, patroon, of nachtmodus), zodat het kind gerustgesteld wordt zonder dat ouders wakker moeten worden of moeten ingrijpen.
Het gebruik moet voorspelbaar zijn, zodat zowel ouder als kind weten wat er gebeurt.

Afgeleid uit:
  – Nachtelijke autonomie
  – Ouders willen niet telkens ingrijpen
  – Nood aan voorspelbaarheid en controle

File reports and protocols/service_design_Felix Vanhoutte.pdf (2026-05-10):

### Service Design – Customer Journey rond slaapregressie

De doelgroep bestaat uit ouders van kinderen tussen 1,5 en 2,5 jaar die slaapregressie ervaren. Uit interviews blijkt dat ouders vooral nood hebben aan rust, voorspelbaarheid, geruststelling en ondersteuning zonder zelf voortdurend wakker te moeten worden.

### 1. Customer Journey

Fase 1 — Vóór het gebruik
De ouders merken dat hun kind moeilijk slaapt, vaker wakker wordt of verlatingsangst toont.

Emoties gebruiker
- Vermoeidheid
- Onzekerheid
- Frustratie
- Schuldgevoel
- Stress tussen partners

Interacties
- Online zoeken naar oplossingen
- Advies vragen aan familie/vrienden
- Kinderarts of kinesist raadplegen
- Bestaande producten proberen
- Avondroutines aanpassen

Touchpoints
- Sociale media
- Parenting forums
- Webshop
- Kinderopvang
- Zorgprofessionals
- Reclame of aanbevelingen

Opportuniteiten
- Betrouwbare begeleiding aanbieden
- Stress verminderen vóór aankoop
- Ouders helpen begrijpen wat slaapregressie is
- Educatie rond routines en prikkels

Fase 2 — Tijdens het gebruik
Het kind wordt ’s nachts wakker en zoekt nabijheid of geruststelling.

Interacties met het fysieke object
- Sensor detecteert huilen
- Product ondersteunt slaapritueel

Gebruikerservaring
Het product moet weinig cognitieve belasting veroorzaken, eenvoudig te begrijpen zijn en geen extra stress creëren tijdens nachtelijke interacties.

Frontstage interacties
- Lichtfeedback
- Geluiden
- Appnotificaties
- Routinevisualisatie
- Kalmerende interactie

Backstage processen
- Data-analyse
- Sensorverwerking
- Synchronisatie tussen toestel en app
- Persoonlijke routine-aanpassingen

Fase 3 — Na het gebruik
Het kind valt opnieuw in slaap of routines verbeteren op langere termijn.

Interacties
- Ouders bekijken slaapinzichten
- Routine aanpassen
- Feedback ontvangen
- Evolutie opvolgen
- Tips krijgen

Gewenste outcome
- Meer controlegevoel
- Minder nachtelijke interventies
- Consistente routines
- Minder stress
- Betere slaapkwaliteit voor gezin

Mogelijke servicecomponenten
- Gepersonaliseerde slaapadviezen
- Community/forum
- Updates via app
- Expert support
- Data-overzicht voor zorgverleners

### 2. Stakeholder Mapping

Primaire stakeholders

Ouders
Hoofdgebruikers die stress en slaaptekort ervaren.

Kind
Eindgebruiker met nood aan veiligheid, voorspelbaarheid en rust.

Secundaire stakeholders

Kinderarts / zorgprofessional
Geeft advies en valideert slaapgedrag.

Grootouders / familie
Bieden emotionele ondersteuning of opvang.

Kinderopvang
Merkt vermoeidheid of gedragsverandering op.

Producent van het product
Verantwoordelijk voor hardware, software en updates.

App/platformbeheerder
Verwerkt data, personalisatie en privacybeheer.

### 3. Service Blueprint

Gebruiker | Frontstage | Backstage | Support
Ouder merkt slaapprobleem | Website/app geeft info | Data en onboarding | Klantenservice
Ouder start avondroutine | Licht/geluid activeert | Routine-algoritme | App synchronisatie
Kind wordt wakker | Sensor reageert | Detectie en verwerking | Cloud/data
Ouder krijgt feedback | Notificatie of slaaprapport | Analyse slaapdata | Expert content
Routine verbetert | Positieve feedback | Persoonlijke aanbevelingen | Updates

### Belangrijke designinzichten

Het product is deel van een ecosysteem: Niet enkel een object ontwerpen, maar een volledige ondersteuningservaring.

Emotionele waarde is cruciaal: Ouders zoeken geruststelling en minder mentale belasting.

Consistentie en routines zijn essentieel: Gewoontes en routines sturen gedrag sterk aan.

Minimale cognitieve belasting: Interacties moeten ’s nachts extreem eenvoudig blijven.

Vertrouwen en privacy: Slaapdata en kindgegevens vereisen transparantie en betrouwbaarheid.

### Conclusie

De waarde van het concept zit niet enkel in het fysieke slaapproduct, maar in de volledige service-ervaring eromheen. Door de customer journey, stakeholderrelaties en service blueprint in kaart te brengen wordt duidelijk hoe verschillende actoren samenwerken om ouders rust, ondersteuning en voorspelbaarheid te bieden tijdens slaapregressie.

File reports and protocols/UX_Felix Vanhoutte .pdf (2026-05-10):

UX & Service Design Challenges

Emotioneel ontwerp:

### 1. Eerste indruk:

dit is waar je rust of stress direct beslist. Dit word bepaald door:
⎯ Vorm (rond vs scherp)
⎯ Kleur
⎯ Lichtintensiteit
⎯ Geluid
⎯ Materiaal
1.1. Vorm:
Vorm beïnvloedt onbewuste associaties.
Ronde vormen worden sneller gelinkt aan veiligheid, zachtheid en benaderbaarheid terwijl Scherpe vormen snel een spanning, precisie en alertheid word gelinkt. Dit komt omdat ons brein scherpe vormen sneller als “gevaar” interpreteert.

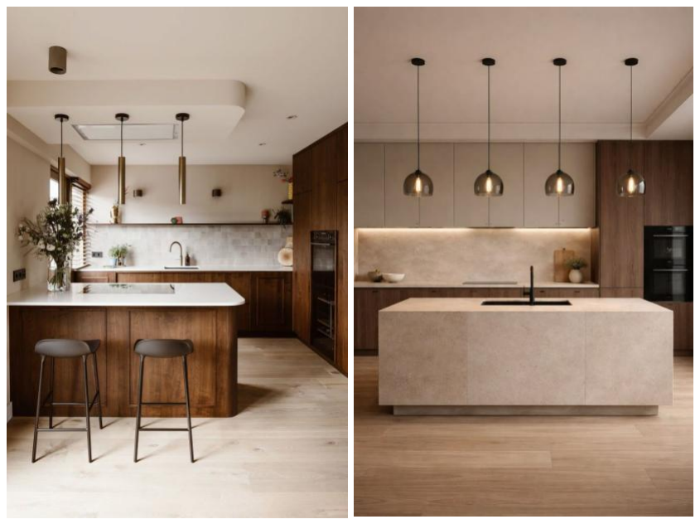
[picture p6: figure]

Ronde vormen | scherpe vormen
1.2. Kleur:
Kleur stuurt meteen emotie en mentale belasting. Lage saturatie brengt rust, hoge saturatie geeft energie of stress. Warme tinten voelen comfortabel, koele zorgen voor focus en afstand.

Te veel contrast leidt tot visuele overload en minder kalmte. Daarom werken zachte blauwtinten, beige en pastel goed, terwijl fel rood met neoncontrast net onrustig maakt.

Consistente kleurcodes (zoals groen = oké) verhogen de betrouwbaarheid en maken gebruik intuïtiever.

1.3. Geluid:
Audio heeft een sterke, vaak onderschatte impact op hoe iets aanvoelt. Lage frequenties werken rustgevend, terwijl hoge, scherpe tonen eerder alertheid of irritatie opwekken. Ook ritme speelt mee: het kan het ademtempo en gedrag van de gebruiker beïnvloeden. Plotse geluiden werken daarbij als een stressprikkel.

Zachte, korte klik- of ademachtige geluiden ondersteunen rust, terwijl een harde piep bij elke interactie snel storend wordt. Subtiele feedbackgeluiden bij bevestiging (zoals wanneer een actie gelukt is) verhogen het gevoel van controle en betrouwbaarheid.

1.4. Materiaal:
Materiaal bepaalt sterk hoe een product aanvoelt: het beïnvloedt comfort, vertrouwen en de ervaren “warmte”. Zachte, warme materialen voelen geruststellend en menselijk, terwijl harde, koude materialen eerder technisch en afstandelijk overkomen.

Mensen koppelen dus automatisch betekenis aan materiaal, los van de functie. Voor rustgerichte producten werken siliconen, textiel en matte afwerkingen goed, terwijl glad, koud plastic of metaal minder geschikt is.

Ook interactie speelt mee: een lichte weerstand bij het indrukken geeft een gevoel van controle en maakt het product betrouwbaarder.

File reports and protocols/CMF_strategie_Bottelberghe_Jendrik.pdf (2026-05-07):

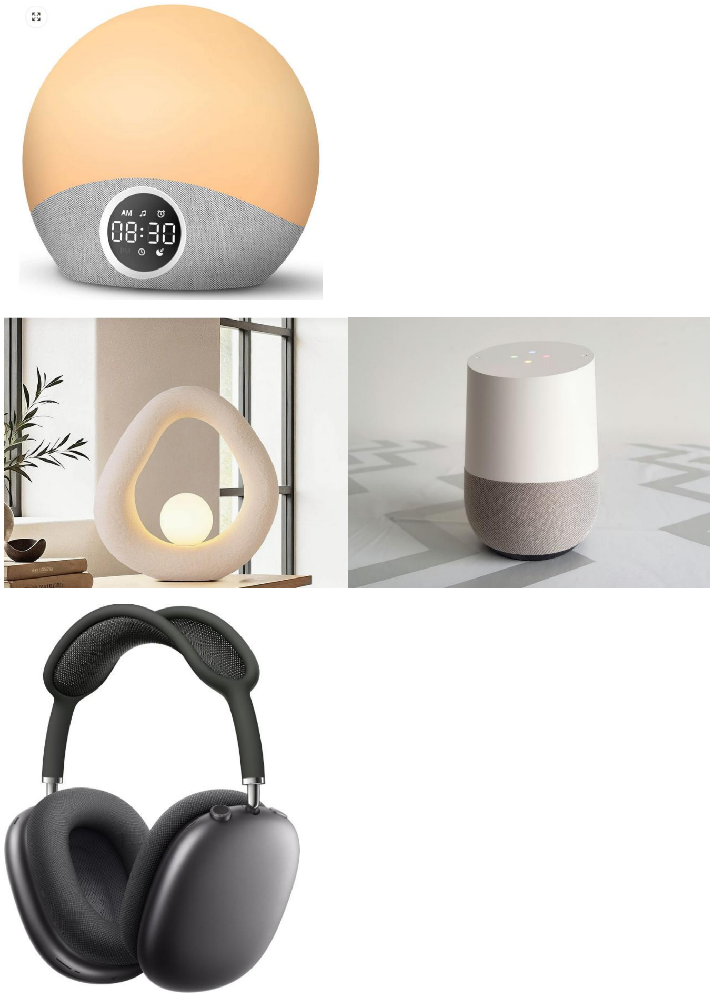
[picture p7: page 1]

| C1 | C2 | M | F1 | F2
| basiskleur | accentkleur | materialen | visuele afwerking | tactiele afwerking
1 | zwart | blauw | PLA (stijf, standaard) | mat | micro-textuur
2 | donkergrijs | rood | TPU (flexibel, grip) | hoogglans | soft-touch
3 | lichtgrijs | geel | PETG (semi-transparant, slagvast) | geborsteld | glad
4 | wit | groen | PVA (oplosbaar, niche) | transparant | ruw
5 | crème | | ABS (impact, industriëler) | satijn | rubberized
6 | | | PC (polycarbonaat, high-end, transparant mogelijk) | translucent | geknurlt
7 | | | PP (licht, flexibel scharnierend) | | geribbeld
8 | | | aluminium (metaal, premium referentie)
9 | | | nylon (PA, slijtvast)
1) User & directe stakeholder
Vorm: minimalistisch, afgerond, harmonieus, organisch Materiaal: lichtgewicht, mat, solide, verfijnd
Gebruik: functioneel, intuïtief, toegankelijk, compact
Emotie: speels, neutraal, elegant
2) Patronen
Organisch, mat, neutraal, afgerond, tastcontrast, warm, verfijnd, kalm

Overeenkomsten = afgerond, organisch, neutraal, mat

CMF-strategie (VizCom)

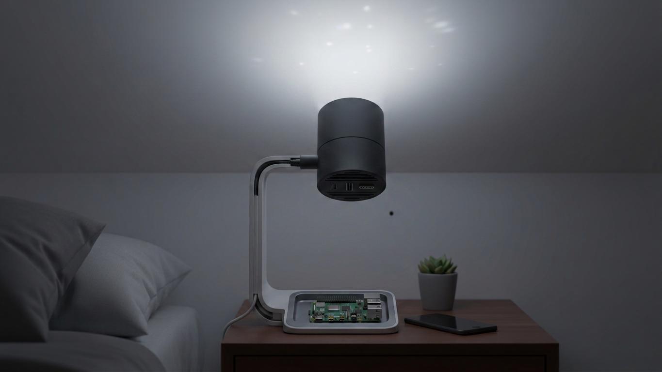
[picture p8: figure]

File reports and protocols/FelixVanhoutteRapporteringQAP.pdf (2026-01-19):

### 1. Doel van het onderzoek

Het doel van dit onderzoek was het in kaart brengen van hoe ouders de spreekfunctie (opgenomen ouderstem) interpreteren en hoe de keuze tussen een oplaadbare batterij en een vaste elektriciteitskabel hun gevoel van betrouwbaarheid, controle en rust beïnvloedt. Het onderzoek combineerde observatie met een Question Asking Protocol (QAP) om de onderliggende mentale modellen en verwachtingen van gebruikers te expliciteren.

### 2. Methode

Het onderzoek werd opgezet als een taak-gebaseerde gebruikstest, gevolgd door QAPinterviews. Er werden twee iteratieve waves uitgevoerd, waarbij telkens hetzelfde scenario werd getest, maar met een andere energievoorziening. In beide waves werd gebruikgemaakt van een fysiek prototype (projector met ingebouwde speaker) en een Figma-template die de app met spreekfunctie simuleerde.

### 3. Resultaten per taak

Taak 1 – Gebruik van de spreekfunctie
Opdracht:
“Stel de spreekfunctie in, zodat jouw kind jouw stem hoort bij bepaalde situaties” Observaties:
- Gebruikers begrepen vrijwel onmiddellijk dat de spreekfunctie bedoeld was om het kind gerust te stellen.
- De meeste gebruikers aarzelden kort alvorens een boodschap in te spreken.
- De ingesproken boodschappen waren meestal kort en geruststellend van toon. Interpretatie:
De spreekfunctie werd intuïtief begrepen, maar riep vragen op over timing en frequentie van gebruik, wat wijst op een sterke behoefte aan controle.

Taak 2 – Activatie en controle van de spreekfunctie
Opdracht:
Gebruikers kozen hoe en wanneer de spreekfunctie geactiveerd moest worden. Observaties:

- Automatische activatie werd met terughoudendheid benaderd.
- Gebruikers gaven de voorkeur aan manuele of voorspelbare activatie. Interpretatie:
Ouders willen ondersteuning, maar geen systeem dat autonoom beslissingen neemt.

Taak 3 – Energievoorziening: batterij vs kabel
Opdracht:
Gebruikers kozen tussen een batterij- of kabeloplossing.
Observaties:
- In wave 1 (batterij) uitten gebruikers bezorgdheid over een lege batterij tijdens de nacht.
- In wave 2 (kabel) werd de vaste stroomvoorziening als betrouwbaarder ervaren, ondanks esthetische nadelen.
Interpretatie:
Betrouwbaarheid primeert duidelijk boven esthetiek in een nachtelijke context.

### 4. Reflectie van de gebruikers

- Gebruikers gaven aan dat constante beschikbaarheid cruciaal is.
- De spreekfunctie werd als waardevol ervaren, mits voldoende controle voor de ouder.
- Onzekerheid over falen (lege batterij) werd als stres verhogend gezien.

### 5. Conclusie

De resultaten tonen aan dat de spreekfunctie intuïtief en betekenisvol is, maar enkel aanvaardbaar blijft wanneer ouders voldoende controle ervaren. Daarnaast blijkt een vaste elektriciteitskabel de voorkeur te genieten boven een batterij, omdat betrouwbaarheid en rust doorslaggevend zijn in een nachtelijke gebruikscontext. Deze inzichten vormen een duidelijke basis voor verdere iteraties en voor het formuleren van design requirements rond controle, voorspelbaarheid en continue beschikbaarheid.

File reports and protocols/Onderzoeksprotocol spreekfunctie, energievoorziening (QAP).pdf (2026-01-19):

Onderzoeksprotocol spreekfunctie, energievoorziening (QAP) Taak-gebaseerde usability test +(QAP)
Onderzoeksthema
Gebruik, interpretatie en ervaren controle bij
1. een spreekfunctie (opgenomen ouderstem)
2. energievoorziening: batterij vs vaste stroomkabel

Doel van het onderzoek
Inzicht krijgen in:
- hoe gebruikers de spreekfunctie begrijpen en gebruiken
- welke mentale modellen zij hebben rond stem-gebaseerde geruststelling
- hoe betrouwbaarheid, rust en controle worden gepercipieerd bij batterij- en kabelgebruik
Het onderzoek focust niet op slaap-effectiviteit, maar op interpretatie en acceptatie.

Methode-overzicht
- Taak-gebaseerde test → observeert wat gebruikers doen
- QAP (follow-up interview) → verklaart waarom dit gedrag plaatsvond QAP wordt altijd gekoppeld aan geobserveerd gedrag.

### 1. Introductie

“Je krijgt straks enkele taken met dit prototype.
Gebruik het zoals jij denkt dat het bedoeld is.
Ik geef geen uitleg tijdens de taken.
Nadien stel ik enkele vragen over wat je deed en waarom.”

Taak 1 – Gebruik van de spreekfunctie (observatie / eventueel TAP)

Materiaal
- Prototype met spreekfunctie
- Interface (mock app of fysieke knop)
- Geen uitleg over timing of ‘juiste’ manier

Opdracht
“Stel de spreekfunctie in, zodat jouw kind jouw stem hoort bij bepaalde situaties” Observatiepunten
- Probeert de gebruiker een boodschap in te spreken?
- Wanneer spreken ze in: meteen / na twijfel / niet?
- Spreken ze spontaan of zoeken ze bevestiging?
- Aarzeling, stoppen, opnieuw beginnen?

### 3. QAP na Taak 1 – Spreekfunctie

(alle vragen refereren expliciet aan gedrag)
Focus:
verwachtingen, emotionele interpretatie, rol van ouderstem Taak 2 – Controle over activatie van de stem

Materiaal
- Scenario’s (verbaal of visueel):
- automatische activatie
- manuele activatie
- vaste opname
Opdracht
“Kies hoe jij dit systeem zou gebruiken in de nacht.” Observatiepunten
- Vermijden van automatische opties?
- Behoefte aan controle?
- Zoeken naar zekerheid of voorspelbaarheid? QAP na Taak 2 – Controle & autonomie
(alle vragen refereren expliciet aan gedrag)

Taak 3 – Energievoorziening kiezen (gedrag)

Materiaal
- Twee scenario’s:
- vaste elektriciteitskabel
- oplaadbare batterij
Opdracht
“Kies hoe jij dit product van stroom zou voorzien en leg het klaar voor gebruik.” Observatiepunten
- Snelheid van keuze
- Twijfel of heroverweging
- Controlerend gedrag (denken aan leeg zijn, veiligheid, kabels)
QAP na Taak 3 – Betrouwbaarheid & rust
Vragen stellen die handelingen in vraag stellen bv “waarom deed je dit, wat verwachte je” of
“Wanneer zou deze keuze een probleem worden?”

Synthesevragen (afrondend, geen QAP)
(duidelijk benoemd als reflectie)
- “In welke situatie zou dit systeem voor jou niet werken?”
- “Wat zou het gebruik van de spreekfunctie moeilijk maken?”
- “Wat moet absoluut vermeden worden om vertrouwen te behouden?”

Rapportering
In het rapport wordt strikt gescheiden:

### 1. Observaties

- wat gebruikers deden
- waar ze aarzelden

### 2. QAP-inzichten

- waarom ze dit deden
- welke verwachtingen en mentale modellen hierachter zaten

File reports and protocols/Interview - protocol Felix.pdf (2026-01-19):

# Interview protocol

## Project informatie

Projectnaam: Slaapregressie bij jonge kinderen (1,5–2,5 jaar).

Slaapregressie bij jonge kinderen is een tijdelijke maar uitdagende fase, waarin hun ontwikkeling het slaappatroon verstoort. Dit project wil inzicht krijgen in de oorzaken en beleving van deze periode bij zowel kind als ouder.
De interviews dienen om praktische en emotionele noden van ouders beter te begrijpen en zo input te verzamelen voor het ontwerpen van een ondersteunend product of dienst.
Het onderzoek maakt deel uit van het opleidingsonderdeel “project gebruiksgericht ontwerpen” binnen de opleiding Industrieel Ingenieur Industrieel Ontwerpen aan de Universiteit Gent, campus Kortrijk, en situeert zich in de discovery fase van het ontwerpproces.

Interviewer: Felix Vanhoutte ( felix.vanhoutte@ugent.be ), Student Industrieel Ingenieur Industrieel Ontwerpen

## Doelstelling en kadering

Slaapregressie bij jonge kinderen is een natuurlijke, maar voor ouders vaak moeilijke fase waarin het slaappatroon van hun kind plots verandert. Deze periodes kunnen leiden tot vermoeidheid en onzekerheid bij ouders, die niet altijd weten hoe ze hier het best mee omgaan.
De interviews hebben als doel meer inzicht te krijgen in de oorzaken, ervaringen en noden die gepaard gaan met slaapregressie. De verkregen informatie zal helpen om een product of dienst te ontwikkelen die ouders ondersteunt tijdens deze periode.
De interviews kaderen binnen de discovery fase van het ontwerpproces, waarin de probleemruimte verkend wordt om later te komen tot relevante ontwerpideeën.

## Respondenten

De respondenten bestaan uit één moeder en één papa, één grootmoeder.

Zij bieden elk een ander perspectief op het thema: de moeders vanuit hun dagelijkse ervaring met slaapregressie en opvoeding, en de grootouder vanuit haar observerende en ondersteunende rol binnen het gezin. Samen geven ze een breed en genuanceerd beeld van hoe slaapregressie wordt beleefd en aangepakt in de praktijk.

De interviews duren 20 min en worden afgenomen van <voeg data toe>

Steekproefomschrijving (N = 3)

pseudonym | respondent type | interview | interview locatie

| datum
Kinesist, 2 kinderen één van 2 jaar en één van 6 jaar | 3 oktober | Telefoonisch
Orthodonthist, 3 kinderen jongste is 1.5 jaar | 10 oktober | thuis
Pensioen, oma van 4 jonge kleinkinderen | 12 oktober | thuis

Sabine De Leeuw

Jean-Louis
Hanssens

Chantal Verbeke

## Onderzoeksvragen

Hoofdonderzoeksvraag:
Hoe ervaren ouders van kinderen tussen 1,5 en 2,5 jaar de slaapregressie en welke ondersteuningsbehoeften hebben zij om deze periode beter te hanteren?
Deelvragen:
1. Welke specifieke gedragsveranderingen en slaapproblemen merken ouders bij hun kind tijdens de 18-maanden- en 2-jarigen slaapregressie?
2. Welke impact heeft de slaapregressie op het dagelijks leven, welzijn en stressniveau van ouders?
3. Welke strategieën en oplossingen passen ouders momenteel toe om de slaapregressie te beheersen?
4. Welke informatie, hulpmiddelen of ondersteuning zouden ouders nuttig vinden om deze periode gemakkelijker door te komen?
5. Zijn er verschillen in ervaring en copingmechanismen tussen ouders van verschillende leeftijden en gezinsstructuren?

## Overzicht van de discussiegids en tijdsinschatting

<Plaats hier een overzicht van de topics die je zal bespreken met een tijdsaanduiding (zie voorbeeld). Daarbij is het belangrijk

- Deel 1 – Introductie
- Deel 2 – Voorstelling Interviewee
- Deel 3 – thema 1: Ervaring van slaapregressie
- Deel 4 – thema 2: Impact op ouders
- Deel 5 – thema 3: Huidige oplossingen en ondersteuningsbehoeften
- Deel 6 – Wrap-up

## Discussiegids

Introductie

Bedankt voor je deelname aan dit onderzoek.

Ik zal starten met het project en mezelf kort voor te stellen.

Ik ben Felix Vanhoutte en ik studeer aan de universiteit Gent campus Kortrijk met afstudeerrichting industrieel ingenieur industrieel ontwerpen.

Dit interview kadert zich binnen het opleidingsonderdeel project gebruiksgericht ontwerpen waarin we onderzoeken hoe ontwerp en technologie maatschappelijke uitdagingen kunnen verlichten.

We willen begrijpen hoe ouders de slaapregressie van hun kinderen ervaren en welke uitdagingen dit met zich meebrengt. Hun ervaringen helpen ons om oplossingen te ontwerpen die echt aansluiten bij hun noden.
We stellen vragen over de slaapproblemen van het kind, de impact op het dagelijks leven en de strategieën die ouders gebruiken. Ook peilen we naar hoe dit nog beter kan.

De input van ouders geeft ons inzicht in hun behoeften en uitdagingen, zodat we oplossingen kunnen ontwikkelen die praktisch en nuttig zijn in hun dagelijkse leven.

Ik ben erg benieuwd naar jouw inzichten en ervaringen. Er zijn geen juiste of foute antwoorden. Ik ben gebaat bij jouw oprechte feedback rond de topics die we zullen behandelen.

Ik wil zeker nog onderstrepen dat alles wat straks in het gesprek aan bod komt in absolute confidentialiteit behandeld wordt. We zijn als studenten aan de Ugent namelijk gebonden aan de Europese privacy richtlijnen. Voor de synthese met de inzichten en aanbevelingen worden individuele meningen sowieso ook geanonimiseerd. Je naam zal met andere woorden niet gekoppeld worden aan specifieke uitspraken. Een meer gedetailleerde beschrijving van onze intenties, verwerking van gegevens, en algemeen beleid kan je nalezen in de ‘Informed Concent’. Voor we van start kunnen met het interview, heb ik jouw expliciet akkoord nodig met dit document.

Ten slotte, had ik je ook graag gevraagd of ik straks dit gesprek mag opnemen met een voice recorder, om ons gesprek te kunnen herbeluisteren wanneer de analyse wordt gemaakt. Uiteraard wordt deze opname niet gedeeld met derden, en verwijderd na afloop van het project. Als u hiermee akkoord gaat, stel ik voordat we het interview beginnen.

----------------------------[invullen informed consent & start recording] ----------------------------

Contextuele vragen

Voorstelling Interviewee

Alvorens we in de materie duiken, wil ik graag eerst even kennismaken.

- Kan je kort jezelf voorstellen en de organisatie waarvoor je werkt?
- Waar zet jouw organisatie vooral op in?
- Kan je me iets meer over je job vertellen?
- Hoe zou je je functie omschrijven? En wat houdt je job precies in?
- Waar ligt voor jou persoonlijk de grootste uitdaging?

Hoofd vragen

In dit project onderzoek ik hoe we ouders kunnen ondersteunen tijdens de slaapregressie van hun jonge kinderen. Wat roept deze uitdaging bij jou op?

- Hoe zou je slaapregressie bij je kind omschrijven?
- Welke typische situaties herken je waarin de regressie zich uit?
- Welke impact heeft dit op het gezin of op jezelf als ouder?
- Wat is volgens jouw de oorzaak?

Thema 1 – Slaappatronen & gedragingen (15 min)
- Hoe verloopt een normale nacht of dutjesperiode tijdens deze regressie?
- Welke gedragsveranderingen merk je bij je kind?
- Welke emoties spelen mee bij je kind en bij jou?
- Zijn er momenten waarop het slapen makkelijker of moeilijker gaat?
- Welke signalen merk je op als je kind onrustig of moe is, maar niet kan slapen?

Thema 2 – Copingstrategieën & routines (15 min)
- Welke methodes of routines gebruik je om je kind te helpen slapen?
- Wat werkt goed, wat minder goed?
- Hoe belangrijk vind je vaste routines of rituelen?
- Zijn er hulpmiddelen, apps of producten die je al gebruikt of zou willen gebruiken?
- Wat zou je willen van een app
- Hoe zorg je ervoor dat je kind ook zelfstandig kan inslapen?

Thema 3 – Technologie & ondersteuning (15 min)
- Ken je digitale hulpmiddelen of apps die bij slaap zouden kunnen helpen?
- Hoe kan technologie bijdragen aan betere slaap voor je kind of meer rust voor jezelf?
- Waar ligt volgens jou de grens tussen ondersteuning en controle?
- Wat betekent een “warme” of “mensgerichte” technologie voor jou in deze situatie?

Wrap-up

Wenst u zelf nog zaken toe te voegen?

De belangrijkste zaken die ik heb geleerd uit dit interview zijn, …
Heb ik het juist begrepen als …?
Wat zijn de belangrijkste elementen waarvan u denkt dat ik die het meest zou moeten onthouden?

Bedankt voor uw tijd!

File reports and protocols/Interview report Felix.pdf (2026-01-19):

## Interview report

Interview 1:

Persoon:

Sabine De Leeuw, ouder van 2 kinderen. Waarvan twee jongens één van 2 en één van 6. Sabine werkt als kinesist.

Belangrijke puntjes:

- “inslapen is niet zozeer het probleem. Het is het systematisch wakker worden.”
- Ze merkt dat het bijna een gewoonte geworden is — een vast patroon dat zich blijft herhalen.
- Volgens haar heeft dit te maken met verlatingsangst, het missen van mama, en soms ook huidhonger. “Hij zoekt letterlijk nabijheid en geruststelling.”
- Ze denkt ook dat hij ’s nachts nog veel prikkels moet verwerken van de dag. “Soms merk ik dat hij gewoon overvol zit in zijn hoofd.”
- Het kind begint vaak te wenen op dat vaste uur. “We hebben geprobeerd om hem even te laten wenen, maar dat werkte niet. Hij hield vol tot iemand kwam. En we hem uiteindelijk in ons bed legde.”
- Soms lijkt bij ons in bed slapen de enige oplossing om de nacht door te komen. “Het is niet ideaal, maar iedereen krijgt tenminste wat slaap.”
- Ze gebruikte eens een knuffelbeer met hartslagfunctie en een nachtlampje om een gevoel van geborgenheid te creëren. Maar dit leek geen effect te hebben.
- Ze benadrukt het belang van een vast avondritueel: badje, pyjama, boekje, zacht licht. “Rust en voorspelbaarheid helpen hem het meest.”
- Sabine zou graag een hulpmiddel hebben dat het kind geruststelt zonder dat de ouders wakker moeten worden. “Als wij telkens opschrikken, raken we zelf ook overprikkeld en worden we vaak ook ongerust.”

Interview 2:

Persoon:

Jean-louis Hanssens, ouder van drie kinderen waarvan de jongste een meisje van 1.5 jaar is en twee ouder broers heeft. Werkt als orthodontist

Belangrijke puntjes:

- Hij noemt slaapregressie “de fase waarin je plots beseft dat slapen niet meer vanzelf gaat.”
- Zijn dochter, normaal een rustige slaper, is nu elke nacht wakker. “Zij huilt niet per se, maar roept gewoon omdat Zij niet meer alleen wil zijn.”
- Typische situaties: wakker worden rond middernacht of vlak na het eerste slaapblok. “Dan is Zij klaarwakker en duurt het soms een uur voor hij terug slaapt.”
- De impact is groot: hij en zijn vrouw zijn moe, gejaagd en minder geduldig met elkaar. “We hebben afgesproken om elkaar niet te verwijten wie de beurt heeft, maar dat is soms moeilijk.” Ook verteld hij dat het moeilijk is om nog energie en aandacht te geven aan zijn andere kinderen. Die deze fase al voorbij zijn
- Volgens hem is de oorzaak vooral verlatingsangst: “Zij begrijpt meer en voelt dat we weg zijn, dat maakt haar onzeker.”
- Overdag slaapt zijn dochter ook korter. “Soms doet zij helemaal geen dutje meer, maar dan is zij tegen 5 uur ’s avonds overprikkeld.”
- Hij merkt dat zijn kind sneller gefrustreerd is en meer houvast zoekt: “Zij wil meer knuffelen, maar duwt je tegelijk ook weg.”
- Emotioneel voelt Jean-Louis zich uitgeput maar ook bezorgd: “Je wilt het goed doen, maar er is geen handleiding.”
- Hun routine: flesje, licht dimmen, zacht muziekje. “Dat werkt meestal, tenzij Zij te veel energie heeft.”
- Wat niet helpt: te snel troosten of hem oppakken. “Dan denkt zij dat zij bij ons hoort te slapen. Soms is de verleiding dan ook groot om haar bij ons in bed te steken. Maar ik probeer consequent te zijn, Het zou desnoods niet eerlijk zijn tegenover mijn andere kinderen.”
- Wat wel helpt: even zacht praten zonder haar op te nemen, of haar een knuffel laten kiezen om mee te slapen.
- Ze gebruiken een babyfoon en een witte-ruis-apparaatje. “Dat helpt een beetje, maar het is geen wondermiddel.”
- Hij vindt technologie handig zolang het niet alles overneemt: “Ik wil niet dat een app bepaalt wat mijn kind nodig heeft.”
- Voor hem betekent een warme technologie iets dat de ouder ondersteunt, niet vervangt bijvoorbeeld een systeem dat signalen geeft wanneer het kind onrustig wordt, zonder te storen.

Interview 3:

Persoon:

Chantal Verbeke, mama van 2 dochters en oma van 4 kleinkinderen. Chantal heeft dus veel ervaring met jonge kinderen met slaapregressie.

Belangrijke puntjes:

- Ze ziet bij haar dochters dat slaapregressie veel invloed heeft: “Ze zijn uitgeput, maar proberen toch consequent te blijven.”
- Ze omschrijft slaapregressie als “een fase waarin kinderen hun rust verliezen omdat hun hoofd te snel groeit.”
- Typische situaties: “Een kind dat overdag perfect vrolijk is, maar ’s nachts alles lijkt te verwerken. Dan huilen ze om niets.”
- De impact op gezinnen is volgens haar enorm: ouders raken vermoeid, en dat beïnvloedt hun humeur, relatie en werk.
- Ze vermoedt dat de oorzaak ligt in de mentale groei van het kind: “Ze leren veel en kunnen dat nog niet plaatsen.”
- Ze merkt dat haar kleinkinderen onrustiger zijn als er veranderingen zijn in de routine — bijvoorbeeld een verhuis, vakantie of nieuwe opvang.
- De kinderen tonen hun vermoeidheid op verschillende manieren: huilen, driftbuien, of juist hyperactief gedrag.
- Ze vindt het belangrijk dat ouders leren rust uitstralen: “Als de ouder gespannen is, voelt het kind dat.”
- Als grootouder probeert ze te helpen door af en toe een nachtje op te passen.
- Ze ziet dat ouders veel druk voelen om “het goed te doen”.
- Technologie vindt ze interessant, maar ook riskant: “Er is al genoeg schermtijd. Een hulpmiddel mag ondersteunen, maar niet afleiden.”
- Voor haar betekent een warme technologie iets eenvoudigs en geruststellends, bijvoorbeeld een rustgevend geluid of zachte verlichting die het kind helpt kalmeren.

## Interviewanalyse – Slaapregressie bij jonge kinderen (1,5–2,5 jaar)

## 1. Doel en context

Deze interviews kaderen binnen de discovery-fase van een ontwerponderzoek aan de Universiteit Gent, opleiding Industrieel Ingenieur Industrieel Ontwerpen.
Het doel was om de ervaringen en noden van ouders en grootouders in kaart te brengen omtrent slaapregressie bij jonge kinderen.
De inzichten helpen om de probleemruimte scherp te stellen en kansen te identificeren voor een product dat zowel het kind als de ouder ondersteunt tijdens nachtelijke onrust.

## 2. Respondentenoverzicht

Naam | Rol | Context / Ervaring
Sabine De Leeuw | Mama van 2 jongens (2 en 6 jaar), kinesist | Persoonlijke ervaring met aanhoudende nachtelijke onrust en hechtingsproblemen
Jean-Louis Hanssens | Papa van 3 kinderen (jongste 1,5 jaar), orthodontist | Ziet slaapregressie als mentale fase; zoekt balans tussen troosten en grenzen stellen
Chantal Verbeke | Mama en oma van 4 kleinkinderen | Beschouwt slaapregressie vanuit breder perspectief: impact op gezinnen en routines

## 3. Thematische analyse

A. Slaapregressie als vast patroon

Alle respondenten beschrijven slaapregressie als herhalend, voorspelbaar gedrag: het kind wordt telkens op hetzelfde uur wakker.

- Sabine spreekt over een vicieuze cirkel van wakker worden, huilen en troosten.
- Jean-Louis benoemt het als een fase waarin slapen niet vanzelf gaat.
- Chantal ziet het als een mentale groeifase waarin het kind ‘zijn rust verliest’.

Analyse: Ouders ervaren slaapregressie niet als tijdelijk ongemak, maar als een terugkerende routine die hun nachtritme structureel verstoort.

B. Oorzaken: emotionele en sensorische prikkeling

De drie respondenten leggen de nadruk op verlatingsangst, huidhonger en overprikkeling.

- Sabine: “Hij zoekt letterlijk nabijheid en geruststelling.”
- Jean-Louis: “Zij voelt dat we weg zijn, dat maakt haar onzeker.”
- Chantal: “Hun hoofd groeit te snel; ze kunnen hun nieuwe ervaringen niet verwerken.”

Analyse: De kern ligt niet in een fysiek probleem, maar in emotionele regulatie en hechting. Dit wijst op de nood aan oplossingen die geborgenheid en rust uitstralen, niet enkel slaap bevorderen.

C. Impact op ouders en gezin

De emotionele en fysieke belasting is groot. Ouders raken vermoeid, prikkelbaar en onzeker.

- Jean-Louis: “We hebben afgesproken om elkaar niet te verwijten, maar dat is soms moeilijk.”
- Chantal: “De invloed op hun humeur en relatie is enorm.”

Analyse: Slaapregressie tast niet enkel het kind aan, maar de gezinsdynamiek als geheel. Ouders zoeken manieren om rust te behouden zonder hun eigen slaap of relatie te verliezen.

D. Huidige strategieën en hulpmiddelen

Ouders hanteren een combinatie van rituelen, troostobjecten en technologische hulpmiddelen, met gemengd succes.

- Sabine gebruikt een beer met hartslag en nachtlampje, zonder merkbaar effect.
- Jean-Louis gebruikt babyfoon en witte-ruis-apparaat, wat beperkt helpt.
- Chantal benadrukt vaste routines, rust uitstralen en consequentie.

Analyse: Er is geen eenduidige oplossing die zowel voor ouder als kind werkt. Hulpmiddelen die alleen geruststellen zonder ouderlijke tussenkomst, blijken het meest gewenst.

E. Verwachtingen t.a.v. technologie

De respondenten staan open voor ondersteunende technologie, zolang die warm en subtiel blijft.

- Jean-Louis: “Technologie mag ondersteunen, niet bepalen.”
- Chantal: “Er is al genoeg schermtijd. Een hulpmiddel moet geruststellen, niet afleiden.”

Analyse: Ouders willen ‘warme technologie’ – hulpmiddelen die intuïtief, stil en geruststellend werken, zonder digitaal te aanvoelen of controle over te nemen.

## 4. Synthese van gebruikersbehoeften

Gebruikersbehoefte | Observatie | Ontwerpimplicatie
Geborgenheid zonder ouderlijke aanwezigheid | Kind zoekt nabijheid en geruststelling | Creëer een systeem dat aanwezigheid simuleert via licht, geluid of hartslagfeedback
Rustige, voorspelbare omgeving | Ouders volgen vast ritueel | Product moet harmonisch integreren in het avondritueel, niet disruptief werken
Ondersteuning zonder overprikkeling | Te veel stimuli werken averechts | Vermijd felle kleuren, geluiden of schermen – focus op zachte zintuiglijke prikkels
Autonomie en controle voor ouders | Technologie mag niet overheersen | Oplossing moet ondersteunen en transparante feedback bieden (bijv. via app of indicator)
Gezinsrust en slaapherstel | Ouders lijden mee onder onrust | Ontwerp moet dubbele rustfunctie hebben: geruststelling voor kind én minder belasting voor ouder

## 5. Conclusie en ontwerpopportuniteiten

De interviews tonen dat slaapregressie diep verankerd zit in emotionele verbinding tussen ouder en kind.
De huidige hulpmiddelen missen empathie en intelligentie — ze troosten niet op het juiste moment of vereisen te veel ouderlijke actie.

Er ligt een duidelijke ontwerpkans in:

Een phygital slaapondersteunend systeem dat op basis van signalen (beweging, hartslag, geluid) subtiele geruststelling activeert zoals zachte projecties, ademhalingslicht of ritmisch geluid zonder de ouders te storen.

Zo’n oplossing zou:

- de emotionele nood aan nabijheid aanspreken,
- overprikkeling verminderen,
- en gezinsrust herstellen.

## 6. How Might We-statement

Hoe kunnen we een warme, niet-digitale technologie ontwerpen die jonge kinderen tijdens slaapregressie geruststelt, zonder dat ouders telkens moeten ingrijpen?

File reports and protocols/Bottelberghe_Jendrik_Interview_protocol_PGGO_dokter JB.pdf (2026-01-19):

# Interview protocol

## Project informatie

Projectnaam: opvoedstress bij verse ouders

Voorafgaand dit interview werd het onderzoek meer afgebakend met als onderwerp : “Hoe kunnen we ouders van huilbaby’s bijstaan bij het opvoeden (voor zowel ouders als kind)?”

Interviewer: Jendrik Bottelberghe ( jendrik.bottelberghe@ugent.be ), Student Industrieel Ingenieur Industrieel Ontwerpen

## Doelstelling en kadering

Dat jonge kinderen gaan huilen is algemeen geweten, maar hoe ga je om met kinderen die meer wenen dan het gemiddelde kind of er gewoon bijna nooit mee stoppen. Nieuwe ouders hebben geen ervaring met het opvoeden van kinderen en kunnen dus geen patronen herkennen van weengedrag. Ook kan het moeilijk zijn in het begin om te weten te komen wat je kan doen zodat je kind stopt met huilen. De doelstelling van de interviews is leren hoe ouders omgaan wanneer hun kind begint te huilen, wat hun ervaringen zijn met huilbaby’s, als ze gebruikt maakten van de huilkalender en wat zij herkenden van patronen in het weengedrag van hun kind(eren). Ook wordt er onderzoek gedaan naar de dynamiek tussen de ouders en hoe zij nu met elkaar omgaan onderhevig aan deze stress.

## Respondenten

De interviews duren 55 minuten en worden afgenomen van 18/10/2025 – 27/10/2025

Steekproefomschrijving (N = 3)

<dit is een voorbeeld tabel met alle participanten voor een studie, vul de tabel zelf in naar gelang de participanten die jij zal bevragen>

pseudonym | respondent type | interview datum | interview locatie
| Ouder van voormalig huilbaby | 25/10/2025 | Adegem
Kwinten
Bottelberghe
Karen Foré | Ouder van voormalig huilbaby | 25/10/2025 | Adegem
Dr Ineke de Kruijff | kinderarts | 27/10/2025 | telefonisch

## Onderzoeksvragen

-hoe kan je als ouders begrip krijgen voor een huilend kind -hoe gaan ouders om met een huilend kind
-welke manieren bestaan om huilen te voorkomen
-welke huilpatronen bestaan er
-zou het begrijpen van de oorzaak van huilen een geruststelling zijn
-hoe gaan alleenstaande ouders om met huilende kinderen zonder mogelijkheid tot afwisselen
-Wordt er genoeg gebruikt gemaakt van bestaande systemen zoals het huildagboek? welke systemen bestaan er?
Waarom niet / hoe zou dit in een nieuwe jas gestoken kunnen worden?
-Wat zou je als advies meegeven aan ouders van huilbaby’s?
-Wat zou een product moeten doen of herkennen om een geslaagde functie te hebben? -hoe kunnen ouders elkaar best helpen? ( afwisselschema)
-Hoe kan een product ervoor zorgen dat ouders gerustgesteld, en tijdelijk ontlast kunnen worden? (informatie, afzondering, geruststelling baby)

## Overzicht van de discussiegids en tijdsinschatting

- Deel 1 – Introductie (5’)
- Deel 2 – Voorstelling Interviewee (5’)
- Deel 3 – thema 1: resultaten enquête(10’)
- Deel 4 – thema 2 : omgaan / beleving van huilen (10’)
- Deel 5 – thema 3 : behoeften (10’)
- Deel 6 – thema 4 : reflectie (10’)
- Deel 6 – Wrap-up (5’)

## Discussiegids

Introductie 5 minuten

Bedankt voor je deelname aan dit onderzoek.

Ik zal starten met het project en mezelf kort voor te stellen.

Ik ben Jendrik Bottelberghe en ik studeer aan de universiteit Gent campus Kortrijk met afstudeerrichting industrieel ingenieur industrieel ontwerpen.

In mijn opleiding heb ik verschillende projecten waarbij ik rond een gegeven thema een nieuw product moet ontwerpen. Dit jaar is dit niet anders. In het vak project gebruiksgericht ontwerpen werk ik één schooljaar lang aan hetzelfde product.

Dit jaar waren er 3 verschillende thema’s waarrond gewerkt kon worden, maar ik koos voor het thema ‘opvoedstress bij verse ouders’. Ik heb dit verder afgebakend naar ‘ het begrijpen en omgaan met huilbaby’s.

Het doel van het interview is vooral nieuwe inzichten krijgen vanuit verschillende invalshoeken. Wat is de invloed van de stress op de ouders en op het kind? Hoe moet je omgaan met huilbaby’s? Hoe zorg je dt het voor beide ouders draaglijk blijft om verder te gaan?

In dit interview zal ik vooral ingaan over de handelingen die ouders doen en wat ze in de plaats beter zouden doen, welke manieren al bestaan om ouders bij te staan, welke manieren beter kunnen en hoe en wat een product het best moet doen om de opvoedstress te verlichten.

Ik ben erg benieuwd naar jouw inzichten en ervaringen. Er zijn geen juiste of foute antwoorden. Ik ben gebaat bij jouw oprechte feedback rond de topics die we zullen behandelen.

Ik wil zeker nog onderstrepen dat alles wat straks in het gesprek aan bod komt in absolute confidentialiteit behandeld wordt. We zijn als studenten aan de Ugent namelijk gebonden aan de Europese privacy richtlijnen. Voor de synthese met de inzichten en aanbevelingen worden individuele meningen sowieso ook geanonimiseerd. Je naam zal met andere woorden niet gekoppeld worden aan specifieke uitspraken. Een meer gedetailleerde beschrijving van onze intenties, verwerking van gegevens, en algemeen beleid kan je nalezen in de ‘Informed Concent’. Voor we van start kunnen met het interview, heb ik jouw expliciet akkoord nodig met dit document.

Ten slotte, had ik je ook graag gevraagd of ik straks dit gesprek mag opnemen met een voice recorder, om ons gesprek te kunnen herbeluisteren wanneer de analyse wordt gemaakt. Uiteraard wordt deze opname niet gedeeld met derden, en verwijderd na afloop van het project. Als u hiermee akkoord gaat, stel ik voordat we het interview beginnen.

----------------------------[invullen informed consent & start recording] ----------------------------

Contextuele vragen

Voorstelling Interviewee 3’

Alvorens we in de materie duiken, wil ik graag eerst even kennismaken.

- Kan je kort jezelf voorstellen en de organisatie waarvoor je werkt?
- Waar zet jouw organisatie vooral op in?
- Kan je me iets meer over je job vertellen?
- Hoe zou je je functie omschrijven? En wat houdt je job precies in?
- Waar ligt voor jou persoonlijk de grootste uitdaging?
- Waar haal je in je job het meeste voldoening uit?

Hoofd vragen 30’

Dit interview wordt afgelegd in functie van mijn opleiding industrieel ingenieur, waar ik nu rond het thema huilbaby’s werk. Het is mijn doel om een product te ontwerpen dat de stress rond huilbaby’s bij ouders kan verlichten. De manier waarrop ik dit het best doe wordt na mijn onderzoek, dit interview inbegrepen, bepaald. Deze interviews zijn bedoeld om mij inzichten te bieden die ik als ontwerper niet zou krijgen.

Topic 1 (resultaten enquête) 10’
Uit mijn voorafgaande enquête (N=22) kreeg ik duidelijke resultaten die ik met u zou willen bespreken.
Ik vroeg wat op de momenten van het huilen het moeilijkst was voor de ouders. De meest aangeduide antwoorden waren : een gebrek aan slaap, machteloosheid en angst dat er iets mis is.
Als ouders zouden kunnen weten waarom en wanneer hun kind huilt, hoe groot zou die impact kunnen zijn?

Ook vroeg ik welke gevoelens de ouders hadden op die momenten. De ouders ervaarden veel stress, uitputting, onmacht en wanhoop. Wat mij opviel is dat ouders dus minder inzitten met het geluid van het wenen, maar eerder met de oorzaken die het huilen zouden veroorzaken. Ook las ik dat er een sterke associatie is tussen moeders met postpartum depressie en moeders van huilbaby’s. (Radesky, 2013)

Om zelf kalm te blijven waren de opties om zich af te zonderen (even weggaan en afwisselen met partner) het populairst. Dit loopt hand in hand met de antwoorden op de vraag ‘Wat had u op dat moment het meeste nodig’, waarop de meerderheid antwoordde met praktische hulp en rust.
Wat is de beste manier om als ouder op zo’n moment rust te nemen. Kunnen ze hun kind 10 minuten alleen laten?

Ongeveer 70% gaf toe dat het huilgedrag invloed had op de relatie met hun partner ( 59.1% tijdelijk, 9.1% langdurig). Dit komt ook terug uit extern onderzoek waaruit blijkt dat zowel de relaties tussen kind tot ouders, als ouder tot ouder lijdt onder de opvoedstress. (räihä, 2002)

Zouden schematische interacties dit tegen kunnen gaan?
Ik denk aan een gepland uur waarbij ouders tijd maken voor elkaar. (samen koken of een wandeling maken)

Topic 2 (huilen) 10’

Ik las het interview met cyberpoli waar dokter Karola de Graaf en u aan deelnamen en las dat in 95 % van de gevallen er geen medische oorzaak was. Stel dat er iets komt dat ouders gerust zou stellen wanneer hun kind huilt, Is het dan belangrijk om met je kind naar een huisarts te gaan bij overmatig huilgedrag?

Hoe groot is volgens u de rol die ouderlijke stress speelt bij het huilgedrag van de baby? Klein : welke factoren spelen dan wel een significante rol?
Groot: Hoe groot dan? Kan een huilbaby theoretisch zijn status als huilbaby ( 3 weken, 3 dagen meer dan 3 uur huilen) verliezen met stressbestendige ouders?

Welke adviezen geeft u aan ouders die geen medische oorzaak vinden maar emotioneel uitgeput zijn?

Ziet u een nood aan meer focus op het welzijn van de ouder zelf, en niet enkel op het kind?

Stel dat er een hulpmiddel of systeem zou bestaan dat ouders helpt hun baby sneller tot rust te brengen — wat zou dat volgens u moeten doen of voorkomen?

Wat zijn volgens u de valkuilen van veel bestaande hulpmiddelen (zoals wipstoeltjes, white noise, draagzakken, apps…)?

Topic 3 (behoeften) 10’

Ziet u eerder nood aan fysieke ondersteuning (vb. wieg, draaghulp, sensorisch hulpmiddel) of mentale/emotionele ondersteuning?

Hoe belangrijk vindt u ouderlijke ontspanning of co-regulatie in het verminderen van huilgedrag?

Als u mocht meedenken met een ontwerpteam: wat zou voor u het belangrijkste uitgangspunt zijn?

Wat zou u zelf het liefst zien ontstaan om deze gezinnen écht te ondersteunen?

Wrap-up 5’

Wenst u zelf nog zaken toe te voegen?

De belangrijkste zaken die ik heb geleerd uit dit interview zijn, …
Heb ik het juist begrepen als …?
Wat zijn de belangrijkste elementen waarvan u denkt dat ik die het meest zou moeten onthouden?

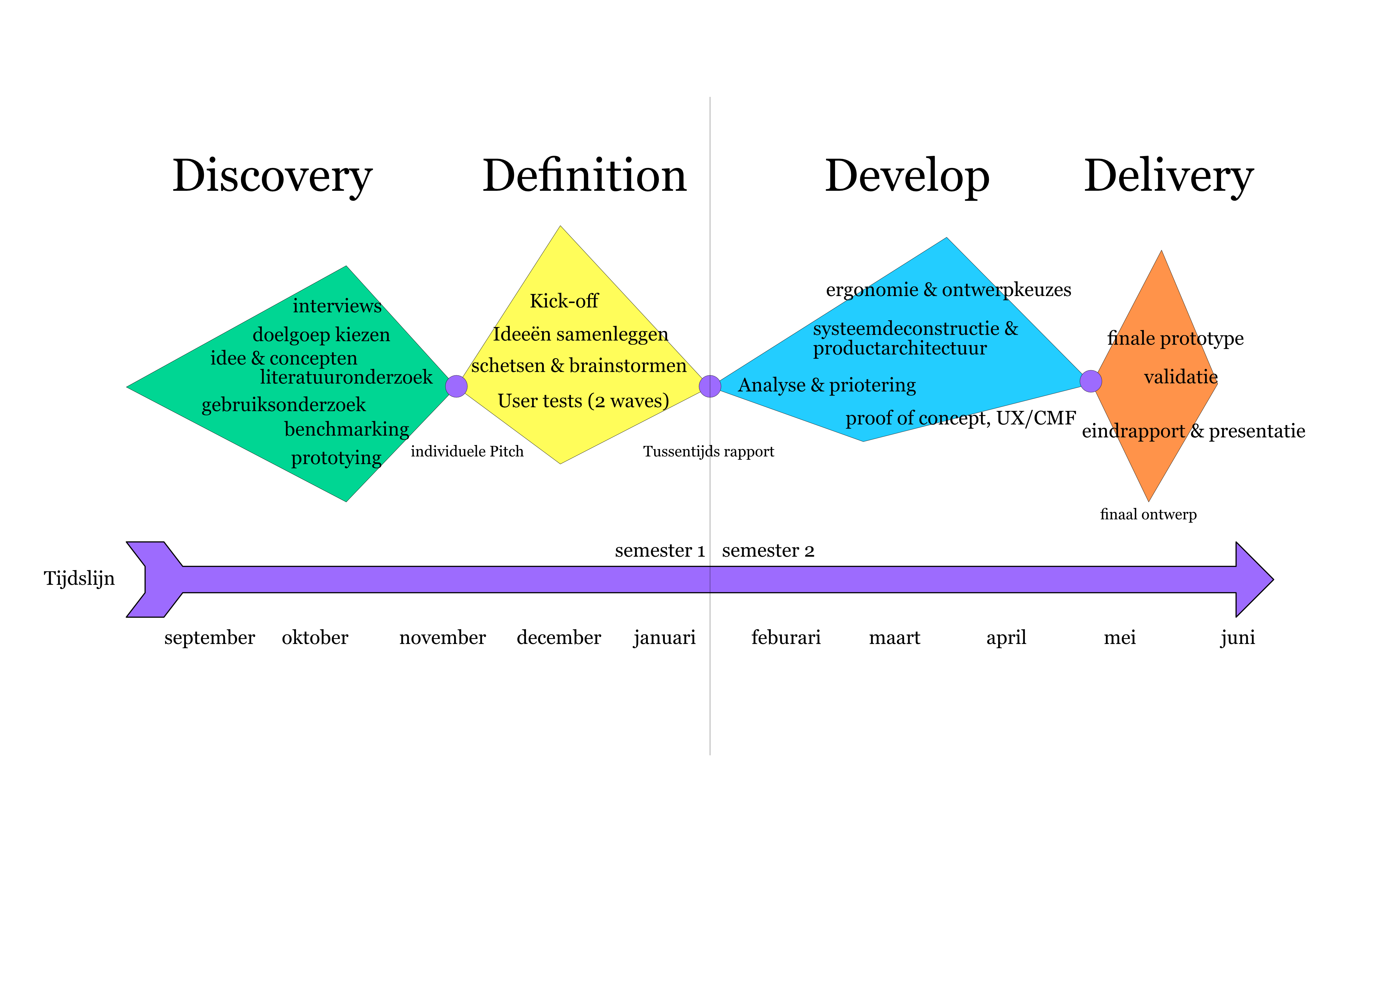
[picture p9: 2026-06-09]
img/Double_Diamond.jpg

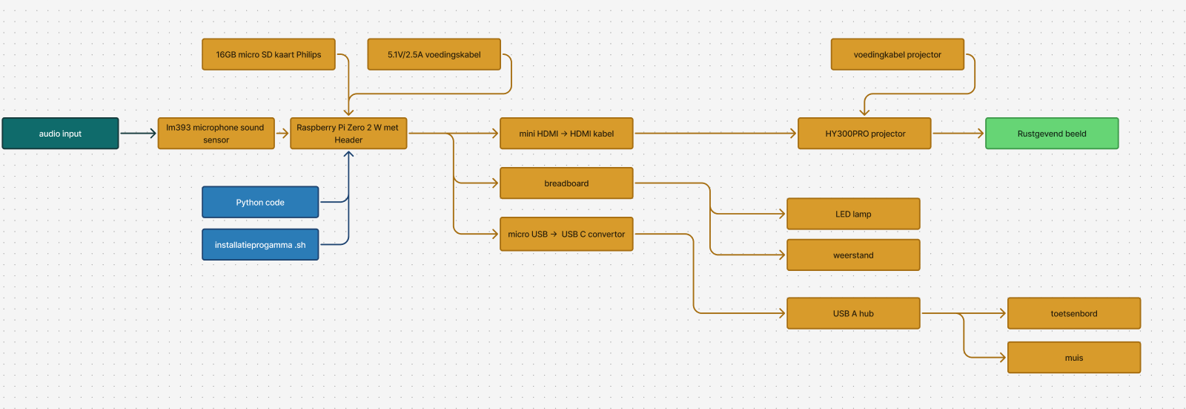
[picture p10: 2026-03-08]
img/productarchitectuur_develop_1.png

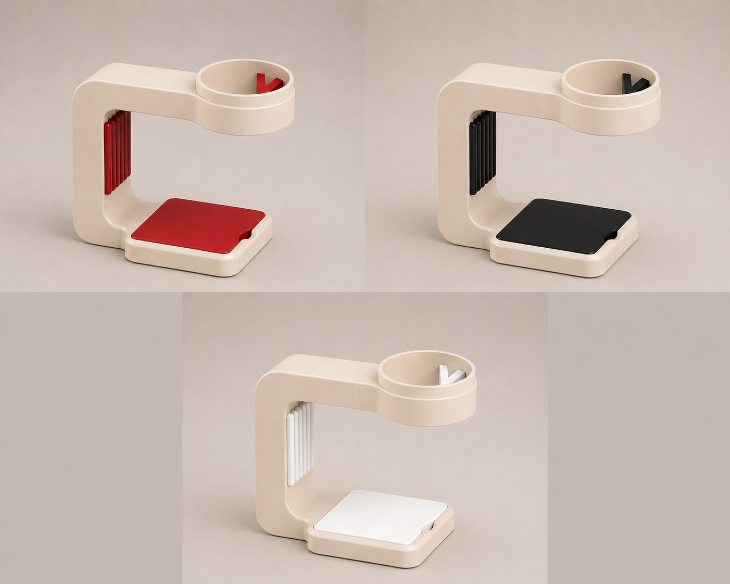
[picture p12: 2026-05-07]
img/AI_render_multicolor.png

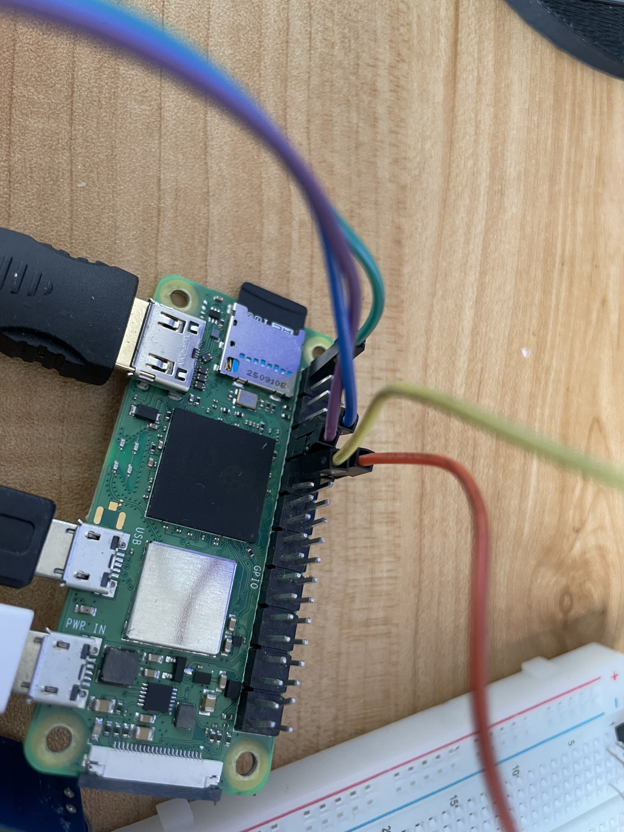
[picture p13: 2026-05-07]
img/RPI_pins.JPEG

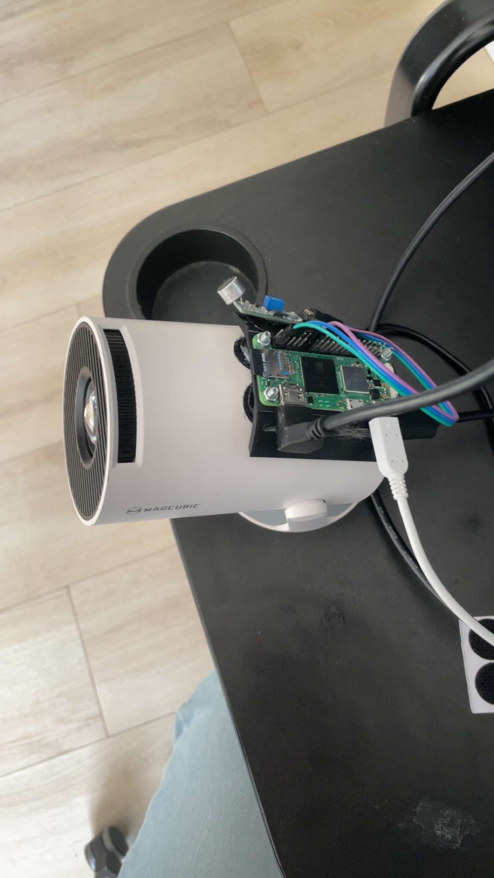
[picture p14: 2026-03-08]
img/afbeelding_samenstelling_2.JPG

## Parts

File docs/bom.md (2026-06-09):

## Bill of materials

- Welk materiaal heb je nodig voor de laatste versie van je prototype?
-PLA
-aluminium
-lijm
-staal
-kunststof

componenten:

- [Mini-videoprojector](https://www.amazon.com.be/-/nl/dp/B0DPHMRS9V/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)
- [raspberry_pi_zero_W](https://www.kiwi-electronics.com/nl/raspberry-pi-zero-wh-header-voorgesoldeerd-3328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)
- [Voeding](https://www.kiwi-electronics.com/nl/raspberry-pi--psu-5-1v-2-5a-microusb-eu-plug-10809)
- [mini_HDMI_kabel](https://www.kiwi-electronics.com/nl/mini-hdmi-kabel-mini-naar-standaard-1-meter-2996)

| **Onderdeel** |**prijs (€)**|
| --- | ---|
| Mini-videoprojector | 54,99 |
| Raspberry Pi Zero  2 W | 20,56 |
| mini HDMI naar HDMI-adapter | 11,90 |
| Voeding (5.1 V 2.5 A) | 8,82 |
| USB C female naar micro USB male adapter | 1,08 |
|USB C naar USB A hub | 7,99 |
|Philips 16GB micro SD | 9,95 |
|Breadboard | 4,99 |
|zelfklevende klitteband | 0,99 |
|video capture card | 5,19 |
| **Totaal** | **126,46** |

**Om dit prototype te bouwen, heeft een maker nodig:**

Basismaterialen (PLA, kunststof, lijm, TPU)

Elektronische componenten (projector, Raspberry Pi, kabels, voeding)

Gereedschap (3D-printer, boormachine, handgereedschap, schroevendraaier)

Softwarebestanden (STL-files, Pi-OS, python programmeertaal)

Basisvaardigheden (3D-printen, elektronica, montage, coderen, 3d-modelleren)

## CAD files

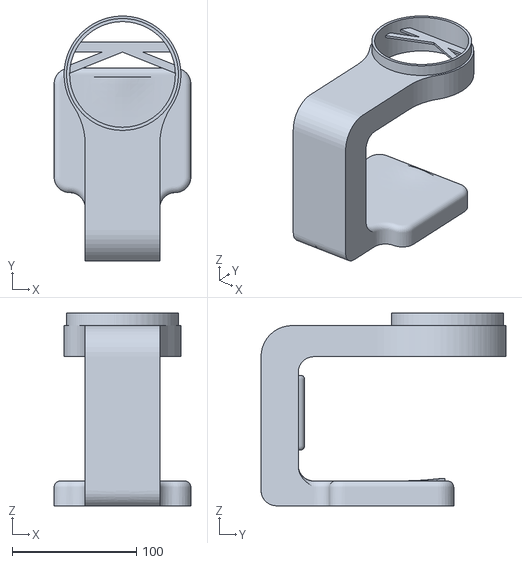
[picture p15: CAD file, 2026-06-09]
cad/projector_steunv2.stl
110.0 x 197.0 x 155.0

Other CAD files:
cad/TopDown/control.prt
cad/TopDown/deksel.prt
cad/TopDown/handvaten.prt
cad/TopDown/holte2.prt
cad/TopDown/holte3.prt
cad/TopDown/links2.prt
cad/TopDown/projector.prt
cad/TopDown/projector_steunv2.prt
cad/TopDown/rechts2.prt
cad/TopDown/steun.prt
cad/oude_modellen/ophangsysteem.prt
cad/oude_modellen/projector_steun.prt
cad/oude_modellen/rasppi steun.prt

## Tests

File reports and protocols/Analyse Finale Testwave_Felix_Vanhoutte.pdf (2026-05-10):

Analyse Finale Testwave
UX & Service Design – Validatie van Prototypevarianten en CMF-Keuzes

### 1. Inleiding

Deze finale testwave had als doel om de definitieve ontwerpbeslissingen te valideren aan de hand van twee prototypevarianten. De centrale onderzoeksvraag was in welke mate het product gevoelens van rust, kalmte en betrouwbaarheid oproept bij ouders met kinderen jonge kinderen.
De test bestond uit:
- semigestructureerde interviews
- observatie tijdens gebruik
- evaluatie van sensorische en emotionele beleving De focus lag op:
- sensorische beleving
- emotioneel ontwerp
- materiaalervaring
- vertrouwen in het product
- algemene gebruikservaring

### 2. Respondenten

Respondent 1: Katrien Klerk
- Leeftijd: 32 jaar
- Moeder van twee kinderen (2 en 5 jaar)
- Raakt snel overprikkeld in drukke huishoudsituaties
- Hecht veel belang aan rust, eenvoud en zachte materialen Respondent 2: charles decoster
- Leeftijd: 29 jaar
- Vader van één kind van 3 jaar
- Gericht op praktische bruikbaarheid en betrouwbaarheid
- Verwacht duidelijke feedback en intuïtieve interactie

### 3. Prototypevarianten

Variant A
CMF-keuzes
- Roomwit basiskleur
- Matte afwerking
- Afgeronde vormen
- Soft-touch materiaal
Doelstelling Een rustige, warme en toegankelijke uitstraling creëren die kalmte en comfort oproept.

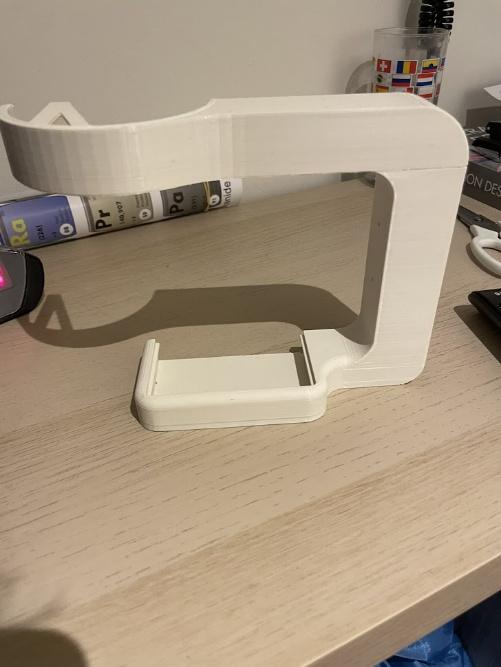
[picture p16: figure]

Variant B
CMF-keuzes
- Zwarte behuizing
- Hoogglans accenten
- Hardere kunststofafwerking
- Strakkere geometrische lijnen

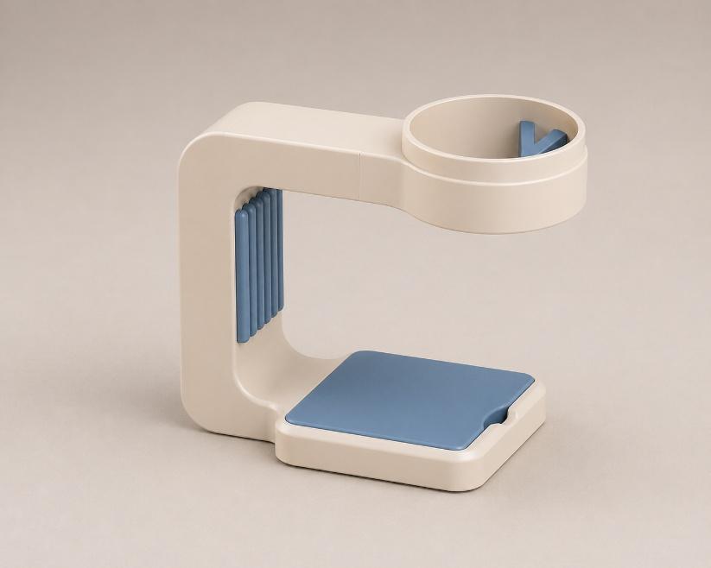
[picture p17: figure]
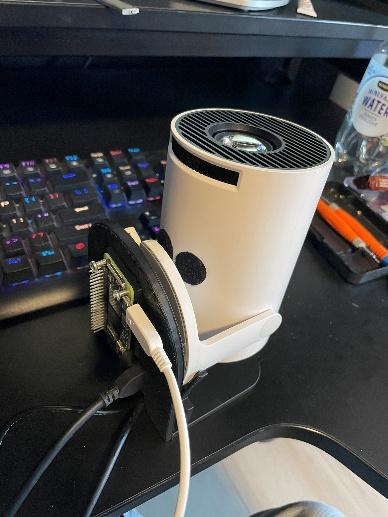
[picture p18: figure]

### 4. Verantwoording van de CMF-keuzes

De CMF-keuzes zijn gebaseerd op inzichten uit de eerdere CMF-analyse. De volgende elementen werden bewust toegepast:
- afgeronde vormen
- matte oppervlakken
- neutrale kleuren
- tactiele zachtheid
- organische vormtaal
Deze dragen bij aan:
- lagere cognitieve prikkels
- verhoogd comfort
- emotionele rust
- toegankelijkheid voor jonge ouders Bewust vermeden:
- sterke kleurcontrasten
- scherpe vormen
- harde glanzende materialen
Deze worden sneller geassocieerd met stress, alertheid of afstandelijkheid.

### 5. Analyse van de Interviews

### 5.1 Eerste Indruk

Katrien
- Reageerde onmiddellijk positiever op Variant A
- Omschreef deze als: “zachter”, “vriendelijker”
- De matte afwerking en afgeronde vormen zorgden voor een rustiger en minder dominant uiterlijk
- Over Variant B: “Het voelt meer als een toestel dan als iets rustgevends.”
Loïc
- Vond Variant B aanvankelijk “professioneler” door de donkere kleur en glans en simpelheid.

- Na langere interactie: “De glans en scherpere lijnen geven iets afstandelijks.”
- Variant A werd uiteindelijk aangenamer tijdens langdurig gebruik

### 5.2 Sensorische Beleving

Visuele ervaring
Beide respondenten ervaarden:
- matte afwerking als rustgevender
- neutrale kleuren als minder vermoeiend
- afgeronde vormen als veiliger en toegankelijker
Variant B werd sneller geassocieerd met technologie en alertheid, niet met ontspanning.

Tactiele ervaring
Katrien
- Sterk positief over soft-touch materiaal van Variant A
- “Het voelt warmer en comfortabeler aan.”
- Hard plastic voelt sneller “koud” of “goedkoop” Loïc
- Grip en controle zijn cruciaal
- “Je hebt sneller vertrouwen als iets stevig en gecontroleerd aanvoelt.”
- Matte oppervlakken gaven meer controle tijdens gebruik

### 5.3 Emotioneel Ontwerp

Variant A riep vooral op:
- rust
- kalmte
- toegankelijkheid
- comfort
De organische vormtaal en subtiele materiaalovergangen verminderden de technische uitstraling.

Variant B riep eerder op:
- precisie
- technologie
- controle
Maar miste:
- warmte
- rust
- zachtheid

### 5.4 Vertrouwen en Betrouwbaarheid

Katrien
Vertrouwen ontstond door:
- voorspelbaar gedrag
- zachte maar duidelijke feedback
- eenvoudige interactie
Variant A voelde logischer en rustiger aan. Loïc
Koppelde betrouwbaarheid aan:
- stabiliteit
- grip
- consistente feedback
Variant A voelde ondanks de zachtere uitstraling toch betrouwbaar door de tactiele controle.

### 6. Belangrijkste Inzichten

Wat werkte goed?
- Matte oppervlakken verminderden visuele drukte
- Afgeronde vormen verhoogden toegankelijkheid
- Soft-touch materialen verhoogden comfort
- Neutrale kleuren ondersteunden rust
Wat werkte minder goed?
- Hoogglans accenten trokken te veel aandacht
- Scherpere lijnen verhoogden de technische uitstraling
- Donkere kleuren maakten het product afstandelijker

### 7. Finale Ontwerpbeslissing

Op basis van de finale testwave werd gekozen om verder te werken met de eigenschappen van Variant A.
Definitieve keuzes
- Matte afwerking
- Afgeronde organische vormtaal
- Neutrale lichte kleur
- Zachte tactiele afwerking Deze combinatie riep het sterkst op:
- rust
- kalmte
- betrouwbaarheid
bij de doelgroep van jonge ouders.

### 8. Conclusie

De finale gebruikerstest toont aan dat kleine CMF-details een grote invloed hebben op de emotionele gebruikerservaring.
Vooral:
- materiaalgevoel
- visuele zachtheid
- tactiele controle
bleken essentieel om rust en vertrouwen op te roepen.
De resultaten bevestigen dat emotional design niet enkel bepaald wordt door functionaliteit, maar sterk gestuurd wordt door subtiele sensorische en materiële keuzes.

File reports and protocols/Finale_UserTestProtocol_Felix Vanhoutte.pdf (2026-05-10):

# Finale User Test – UX & Service Design Validatieprotocol

Doel van deze finale user test is het valideren van de definitieve ontwerpbeslissingen aan de hand van meerdere varianten van het product. De focus ligt op gebruikerservaring, emotioneel ontwerp, zintuiglijke beleving en betrouwbaarheid.

### 1. Onderzoeksdoel

Nagaan welke ontwerpvariant het sterkst gevoelens van rust, kalmte en betrouwbaarheid oproept en welke sensorische elementen bijdragen aan een positieve gebruikerservaring.

### 2. Steekproef

Deze test wordt uitgevoerd met minimaal de groepsgrootte + 2 respondenten. De respondenten moeten representatief zijn voor de doelgroep.

### 3. Testopstelling

- Individuele interviews
- Controlled testing context
- Testduur: ongeveer 20–30 minuten per deelnemer
- Gebruik van prototype(s) of mock-ups

### 4. Testscenario

De deelnemer gebruikt het product in een realistische context. Tijdens de interactie observeert de onderzoeker gedrag, reacties en twijfelmomenten.

### 5. Observatiepunten

- Momenten van twijfel of frustratie
- Reacties op geluid, licht, materiaal en vorm
- Vertrouwen in het product
- Algemene rust of stress tijdens gebruik

### 6. Interviewvragen

Algemene ervaring:
1. Wat was je eerste indruk van het product?
2. Hoe voelde je je tijdens het gebruik?
3. Voelde het product rustgevend of eerder druk aan?

4. Had je het gevoel controle te hebben tijdens het gebruik?

Visuele beleving:
5. Hoe ervaar je de kleuren en vormgeving?
6. Welke elementen stralen volgens jou rust uit?
7. Waren er visuele elementen die storend aanvoelden?

Tactiele beleving:
10. Hoe voelt het materiaal aan?
11. Past het materiaal bij de functie van het product?

Betrouwbaarheid:
12. Vertrouw je dat het product correct werkt?
13. Waren er momenten waarop je twijfelde aan het systeem?

Vergelijking varianten:
14. Welke variant spreekt je het meeste aan en waarom?
15. Welke variant voelt het meest rustgevend?
16. Welke variant voelt het meest betrouwbaar?

### 7. Evaluatieschaal

Laat deelnemers onderstaande aspecten scoren van 1–7:
- Rustgevendheid
- Kalmte
- Betrouwbaarheid
- Gebruiksgemak
- Visueel comfort
- Tactiel comfort

### 8. Analyse

Vergelijk de antwoorden en scores van de verschillende respondenten. Zoek naar terugkerende patronen, positieve reacties en pijnpunten. Gebruik deze inzichten om de finale ontwerpbeslissingen te onderbouwen.

### 9. Conclusie

Vat samen welke ontwerpvariant het best presteert en welke sensorische of UX-elementen het sterkst bijdragen aan rust, kalmte en betrouwbaarheid.

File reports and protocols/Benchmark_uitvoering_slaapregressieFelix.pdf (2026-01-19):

## Benchmarkonderzoek — Slaapregressie (1,5–2,5 jaar)

Project: Slaapregressie bij jonge kinderen

Vak: Project gebruiksgericht Ontwerpen — Universiteit Gent, Campus Kortrijk

## Onderzoeksdoel & -vraag

Doel: In kaart brengen hoe bestaande producten en diensten ouders ondersteunen bij slaaproutines en slaapproblemen van peuters (1,5–2,5 jaar), en welke ontwerpprincipes werken of tekortschieten.

Onderzoeksvragen: (1) Welke oplossingen bestaan er? (2) Hoe communiceren ze routines/feedback? (3) Hoeveel rekening houden ze met de context en stress van ouders?
(4) Welke principes nemen we mee?

## Transparantie van het protocol

De uitvoering volgt het eerder opgestelde benchmarkprotocol: selectie van 10 producten, gestandaardiseerde analyse per product en synthese t.o.v. vooraf gedefinieerde evaluatiecriteria (gebruiksgemak, feedback, betrouwbaarheid, motivatie, integratie, autonomie, privacy).

## Sampling & selectie

Doelgerichte steekproef van 10 oplossingen (mix van fysieke producten en apps) met hoge relevantie voor peuterslaap en voldoende publieke documentatie.

## Productanalyses (10)

### Hatch baby

https://www.hatch.co/learn/baby

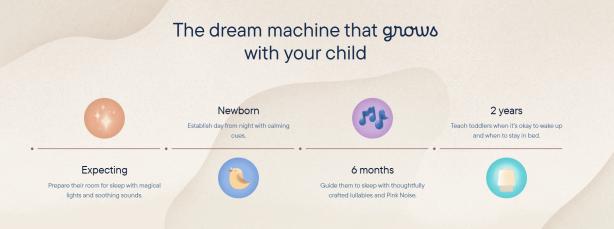
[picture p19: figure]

Beschrijving: De Hatch baby is een slim nachtlampje dat geluid, licht en een “time-to-rise”-functie combineert om slaaproutines te ondersteunen. Via de app kunnen ouders schema’s instellen voor slapen, rusten en opstaan. Het toestel gebruikt zachte kleur- en geluidsveranderingen om voorspelbaarheid te creëren. Gericht op pasgeborene tot 2 jarige kinderen, met nadruk op routine-consistentie.

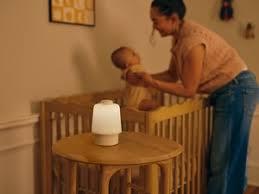
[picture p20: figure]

Sterktes:

- Combinatie licht/geluid/routine in één toestel
- Time-to-rise visuele cue voor peuters
- App-bediening en schema’s

- Er kan via de app gechat worden met experten.

Zwaktes:

- Afhankelijk van stroom en (soms) wifi/app
- Te veel opties kunnen complex aanvoelen
- je moet een abonnement betalen.
- prijzig

### Tommee Tippee Groclock — slaaptrainerklok

https://www.tommeetippee.com/en-gb/product/groclock-sleep-trainer-clock

Beschrijving: Kleuren en pictogrammen tonen ‘slapen’ vs ‘opstaan’ voor kinderen die nog geen klok lezen.

Sterktes:

- Eenvoudig, scherm gebaseerd kleurensignaal
- Geen smartphone nodig

Zwaktes:

- Beperkte personalisatie en feedback
- Helderheid en lichtlekkage kunnen storend zijn

### LittleHippo MELLA — ready-to-rise klok

https://littlehippo.com/collections/sleep-trainers/products/mella

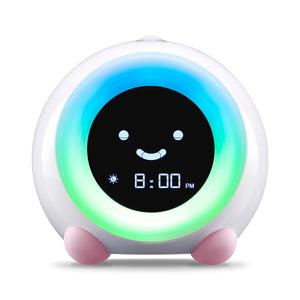
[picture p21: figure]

Beschrijving: De MELLA Sleep Trainer combineert een wekker, nachtlamp en geluidssysteem in één apparaat met kindvriendelijk design. De klok gebruikt kleurveranderingen en gezichtsuitdrukkingen om slaap- en waaktijd aan te geven. Ouders kunnen licht, volume en geluid instellen via knoppen. Het product richt zich op peuters die leren omgaan met vaste routines.

Sterktes:

- Meerdere functies (geluid, licht, timer)
- Kinderlijke vormgeving verhoogt acceptatie
- Easy to use

Zwaktes:

- Niet innovatief

- Geen feedback
- Duur voor de beperkte functies die het product heeft
- Kwaliteitsvariatie volgens reviews

### ZAZU SAM — sleeptrainer + nachtlicht

https://zazusleep.com/collections/sleep-trainer/products/sam

Beschrijving: SAM de slaaptrainer werkt met een duidelijk stoplichtsysteem: rood betekent slapen, oranje “bijna opstaan” en groen “wakker”. De klok bevat een digitaal display en nachtlichtfunctie. SAM is eenvoudig in gebruik maar vraagt enige gewenning bij het instellen. Hij helpt jonge kinderen visueel begrijpen wanneer het tijd is om in bed te blijven.

Sterktes:

- Duidelijke kleurstappen (ook pre-wake oranje)

Zwaktes:

- Knoppen/instellingen vragen gewenning
- Batterij/adapter afhankelijk

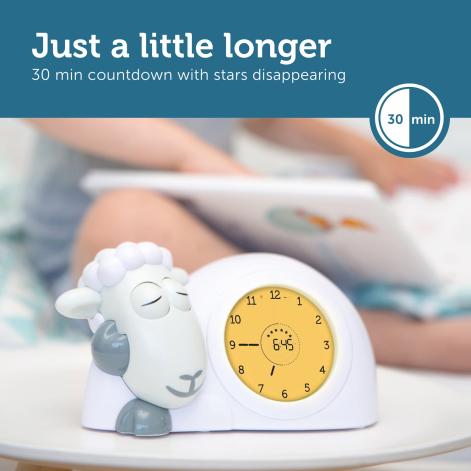
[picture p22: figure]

- Niet geschikt voor kinderen van 1.5 jaar. Eerder voor peuters vanaf 3 jaar.

### Yoto Player — schermvrije audio

https://eu.yotoplay.com/yoto-player

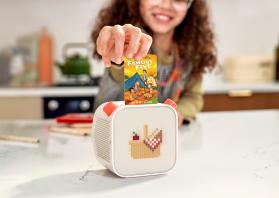
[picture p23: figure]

Beschrijving: De Yoto Player is een schermvrije audio-speler waarop kinderen zelfstandig verhalen, muziek of rustgevende geluiden kunnen afspelen via fysieke kaarten. Ouders kunnen bedtimeroutines instellen of “good morning”- en “sleep”-modi activeren. Het toestel heeft een vriendelijk ontwerp en LED-icoontjes voor feedback. De focus ligt op zelfstandigheid en rustige slaapvoorbereiding.

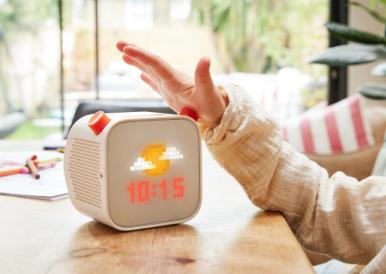
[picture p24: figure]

Sterktes:

- Schermvrij, kind kan zelfstandig bedienen
- Grote community en veel content
- Verhalen kalmeren kinderen

Zwaktes:

- Extra kaarten nodig (kost)
- Pas voor kinderen vanaf 3 jaar
- Niet specifiek slaaptrainer (wel routine-ondersteuning)

### Moshi — sleep & mindfulness app voor kinderen

https://www.moshikids.com/research/

Beschrijving: Moshi is een mobiele app die verhaaltjes, meditatie-audio en rustgevende muziek aanbiedt om kinderen te helpen ontspannen en inslapen. De verhalen zijn specifiek ontworpen om stress te verlagen en worden ondersteund door onderzoek. De app bevat honderden verhalen afgestemd op leeftijd en stemming. Ouders kunnen luisteren via telefoon of smart speaker.

Sterktes:

- Onderbouwd met effectstudies/case studies
- Breed aanbod voor verschillende leeftijden

Zwaktes:

- Scherm/telefoon in de slaapkamer nodig
- Geen fysiek toestel
- Abonnementsmodel

### Huckleberry — slaapplanning met SweetSpot

https://huckleberrycare.com/pricing

Beschrijving: De Huckleberry-app helpt ouders slaaproutines optimaliseren door gegevens over dutjes en slaaptijden te analyseren. De unieke “SweetSpot”-functie voorspelt het ideale moment om een kind te laten slapen. De app biedt persoonlijke aanbevelingen en meldingen. Zo leren ouders patronen herkennen die slaapregressie helpen verminderen.

Sterktes:

- Persoonlijke aanbevelingen en alerts
- Bekende ‘SweetSpot’ voor juist inslaaptiming

Zwaktes:

- Datainvoer vereist discipline
- Geen fysieke cue voor het kind zelf

### Nanit Pro + Insights — baby/peuter monitor & analytics

https://nanitnl.nl/products/nanit-pro-camera-babyfoon-met-app?variant=45116570239242 (https://nanitnl.nl/products/nanit-pro-camera-babyfoon-met-app?variant=45116570239242)

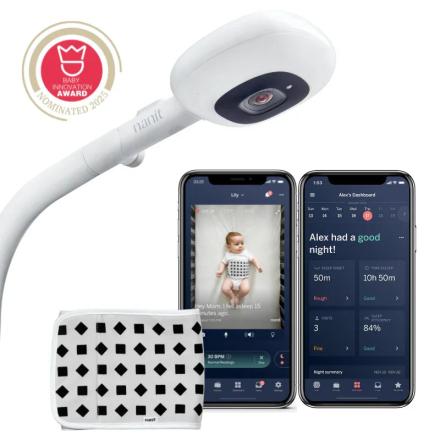
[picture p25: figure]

Beschrijving: De Nanit Pro is een slimme baby- en peutermonitor met HD-camera, slaaptracking en groeianalyse. Via de Insights-app ontvangen ouders rapporten over slaapduur, wakkertijd en nachtelijke patronen. De camera biedt notificaties bij beweging of geluid. De data helpen ouders routines bijsturen.

Sterktes:

- Objectieve slaapstatistieken en trends
- App-notificaties helpen consistentie

Zwaktes:

- Abonnement voor Insights
- Zeer duur
- Camera in slaapkamer roept privacyvragen op

### Owlet Dream Sock (+ Extension/Plus)

https://owletcare.be/nl/products/owlet-dream-sock


Beschrijving: De Owlet Dream Sock is een wearable die hartslag, zuurstofniveau en slaaptrends meet bij jonge kinderen. De data worden via de Dream-app gevisualiseerd, zodat ouders geruststelling krijgen over de slaapkwaliteit. Met uitbreidingen kan het systeem tot peuterleeftijd worden gebruikt. Hoewel vooral medisch geïnspireerd, biedt het ook inzicht in rustpatronen.

Sterktes:

- Veel data.
- Ontvang meldingen over het volgende slaapvenster van uw baby met behulp van voorspellende slaaptechnologie.

Zwaktes:

- Voor baby’s van 0-18 maanden
- Duur

Relevante les: Gezondheidsfeedback kan geruststellen, maar is niet altijd nodig voor gedragstraining.

### Lulla Doll — slaapknuffel met adem/hartritme

https://lulladoll.com/collections/lulla-collection-1/products/lulla-doll

Beschrijving: De Lulla Doll is een zachte knuffel die levensechte adem- en hartgeluiden afspeelt tot 12 uur lang. Ze is ontworpen om nabijheid en veiligheid te simuleren voor baby’s en jonge kinderen. De constante auditieve prikkel werkt kalmerend en bevordert doorslapen. Wasbaar en eenvoudig te gebruiken, maar langdurig gebruik kan sterke slaapassociaties creëren.

Sterktes:

- Gerichte geruststelling en hechtingsgevoel
- Machinewasbaar, eenvoudig in gebruik
- Easy to use

Zwaktes:

- Kan een sterke slaapassociatie creëren
- Geeft geen data.

## conclusie

Het benchmarkonderzoek toont aan dat er veel bestaande oplossingen zijn rond slaaptraining en slaapmonitoring, maar weinig specifiek afgestemd op peuters tussen 1,5 en 2,5 jaar.

De meeste producten:

- zijn óf te technisch en gericht op ouders (monitoring, data),
- óf te eenvoudig en niet voldoende gepersonaliseerd (kleurenklokken).

Er ontbreekt een geïntegreerde, gebruiksvriendelijke oplossing die:

- visuele en auditieve signalen combineert met geruststellende feedback,
- inspeelt op de ouder-kindinteractie,
- en werkt zonder permanente scherm- of app afhankelijkheid.

Voor het verdere ontwerpproces betekent dit dat ontwerpprincipes zoals eenvoud, rust, zintuiglijke signalen, ouderbetrokkenheid en autonomie cruciaal zijn.

De inzichten vormen een duidelijke opportuniteit om een phygital product te ontwikkelen dat zowel slaaproutine als emotionele geruststelling ondersteunt binnen deze specifieke leeftijdsgroep.

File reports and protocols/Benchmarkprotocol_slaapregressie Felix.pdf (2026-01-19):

### Benchmarkprotocol

### Projectinformatie

Projectnaam: Slaapregressie bij kinderen van 1,5 tot 2,5 jaar

Vak: Project gebruiksgericht Ontwerpen — Universiteit Gent, Campus Kortrijk

### Doelstelling en kadering

Het doel van deze benchmarkstudie is om bestaande producten, hulpmiddelen en digitale toepassingen te analyseren die ouders ondersteunen bij slaapproblemen of slaaproutines van jonge kinderen (1,5–2,5 jaar). Deze benchmarking kadert binnen de discovery fase van het project Slaapregressie bij jonge kinderen en heeft als doel inzicht te verwerven in bestaande oplossingen, hun sterke punten, tekortkomingen en ontwerpstrategieën. De inzichten zullen helpen om ontwerpvereisten te formuleren voor een nieuw product dat ouders ondersteunt tijdens periodes van slaapregressie.

### Onderzoeksvragen

1. Welke bestaande producten of hulpmiddelen helpen ouders omgaan met slaapproblemen bij jonge kinderen?
2. Hoe communiceren deze producten feedback, routines of slaapinformatie naar de ouder?
3. In welke mate houden bestaande oplossingen rekening met de emotionele belasting en context van ouders?
4. Welke ontwerpprincipes kunnen we overnemen of verbeteren in ons eigen concept?

### Onderzoeksopzet en methodiek

De benchmarking richt zich op minimaal 10 producten of systemen die slaapgedrag bij jonge kinderen ondersteunen. De selectie en analyse gebeurt volgens vaste criteria en een gestandaardiseerd sjabloon, zodat resultaten vergelijkbaar en herhaalbaar zijn.

### Selectiecriteria voor producten

- Relevantie: het product ondersteunt slaapgedrag of slaaphygiëne van jonge kinderen (1–3 jaar).
- Context: bedoeld voor thuisgebruik of slaapomgeving van het kind.
- Toegankelijkheid: het product is commercieel beschikbaar of gedocumenteerd (handleiding, reviews, website).
- Variatie: selectie bevat zowel fysieke producten (bv. nachtlampjes, knuffels, slaaptrainers) als digitale oplossingen (apps, smart monitors).

- Gebruikersgerichtheid: er wordt gekeken naar gebruiksgemak, betrouwbaarheid en feedbackmechanismen.

### Samplingstrategie

Methode: doelgerichte steekproef op basis van relevantie binnen het domein. Steekproefgrootte: minimaal 10 producten.
Bronnen: officiële productwebsites, gebruikersreviews, academische papers, YouTube-demo’s, appstores.

### Materiaal en tools

- Benchmarktemplate (Excel of Miro)
- Google Scholar en productwebsites
- Gebruikersrecensies (Amazon, Bol.com, App Store)
- Producthandleidingen en foto’s
- Kwalitatieve analyse-tool (bijv. Miro of Notion)

### Stappenplan (protocol)

1. Vooronderzoek : Definieer relevante productcategorieën en stel selectiecriteria vast.
2. Selectie: Verzamel 15–20 mogelijke producten en filter tot 10 op basis van relevantie.
3. Productanalyse: Vul per product het benchmarksjabloon in met rubrieken: naam, doelgroep, gebruikservaring, feedback, sterktes, zwaktes, lessen.
4. Dataverzameling: Voeg screenshots, foto’s, beschrijvingen en bronnen toe aan dataset.
5. Analyse en synthese: Vergelijk alle producten op evaluatiecriteria, identificeer patronen, formuleer ontwerpimplicaties.

### Evaluatiecriteria

Criterium | Beschrijving | Relevantie voor ontwerp
Gebruiksgemak | Mate van eenvoud, intuïtieve bediening | Ouders moeten het product vlot kunnen gebruiken, zelfs bij vermoeidheid
Feedback & communicatie | Type en duidelijkheid van terugkoppeling | Transparante communicatie over status of voortgang van het kind
Betrouwbaarheid | Technische stabiliteit, connectiviteit, onderhoud | Ouders vertrouwen op constante werking

Motivatie & geruststelling In welke mate helpt het product stress verminderen Belangrijk voor emotionele ondersteuning van ouders

Integratie & esthetiek | Hoe past het product in de slaapkameromgeving
Product moet rust
uitstralen en passen bij
context van kind
Autonomie & controle | Balans tussen automatische functies en oudersturing
Ouders behouden gevoel
van controle
Privacy & data | Transparantie over datagebruik
Vertrouwen essentieel bij
kinderdata

### Dataverzameling en analyse

Verzamelde data:
- Beschrijvingen, screenshots, gebruikerservaringen en recensies. Alle bronnen worden geciteerd met URL en datum van consultatie.

Analyse:
- Thematische analyse op basis van de evaluatiecriteria.
- Clustering in Miro op basis van sterktes/zwaktes.
- Samenvattende tabel per criterium.

Synthese:
- Ontwerpimplicaties worden afgeleid (bijv. “multimodale feedback verhoogt vertrouwen”).
- Resultaten worden samengevat in een eindrapport.

### Referentie naar uitkomst

De volledige resultaten worden opgenomen in het Discovery-rapport (Deelopdracht 1) onder de sectie Benchmarkanalyse. Deze analyse vormt een belangrijk uitgangspunt voor het definiëren van de ontwerpvereisten (PRD) en de uiteindelijke conceptpitch (D1.1).

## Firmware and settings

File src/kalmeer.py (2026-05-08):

from gpiozero import DigitalInputDevice, LED
from signal import pause
import subprocess
import os
import threading
import time
import signal
import sys

# ── Configuration ────────────────────────────────────────────────────────────
GPIO_SOUND = 17
GPIO_LED = 27
VIDEO = "/home/wokkel/kalmeer_video.mp4"
LOCK_TIME = 60  # seconds video plays / system stays locked
TRIGGER_WINDOW = 45  # seconds within which triggers must occur
TRIGGERS_NEEDED = 3

# ── Startup checks ───────────────────────────────────────────────────────────
if not os.path.isfile(VIDEO):
    raise FileNotFoundError(f"Video niet gevonden: {VIDEO}")

if not os.access("/dev/fb0", os.W_OK):
    raise PermissionError(
        "Geen schrijfrechten op /dev/fb0.\n"
        "Voer uit: sudo chmod a+w /dev/fb0\n"
        "Of maak een udev regel aan voor een permanente oplossing."
    )

# Verberg terminal cursor en wis scherm
subprocess.run(["setterm", "--cursor", "off"], stderr=subprocess.DEVNULL)
subprocess.run(["clear"], stderr=subprocess.DEVNULL)

# ── Hardware ─────────────────────────────────────────────────────────────────
sensor = DigitalInputDevice(GPIO_SOUND, pull_up=False, bounce_time=None)
led = LED(GPIO_LED)

# ── Shared state (always access inside `state_lock`) ─────────────────────────
state_lock = threading.Lock()
locked = False
player = None
timer = None
trigger_times = []
_running = True  # Bepaalt of achtergrondthreads actief blijven
TRIGGER_COOLDOWN = 10  # seconds between accepted triggers
last_trigger_time = 0.0


# ── Display helpers ───────────────────────────────────────────────────────────
FB_DEVICE = "/dev/fb0"


def _fb_size():
    """Geeft de totale grootte van de framebuffer in bytes."""
    try:
        with open("/sys/class/graphics/fb0/virtual_size") as f:
            w, h = map(int, f.read().strip().split(","))
        with open("/sys/class/graphics/fb0/bits_per_pixel") as f:
            bpp = int(f.read().strip())
        return w * h * (bpp // 8)
    except Exception:
        return 1920 * 1080 * 4  # fallback: Full HD 32-bit


def screen_off():
    """Maakt de framebuffer zwart -> volledig zwart scherm op de projector."""
    try:
        size = _fb_size()
        with open(FB_DEVICE, "wb") as fb:
            chunk = b"\x00" * (1024 * 1024)
            written = 0
            while written < size:
                block = min(len(chunk), size - written)
                fb.write(chunk[:block])
                written += block
    except Exception as e:
        print(f"screen_off fout: {e}")


def screen_on():
    """Ververs de tty zodat mpv een schoon scherm krijgt."""
    subprocess.run(["chvt", "2"], stdout=subprocess.DEVNULL, stderr=subprocess.DEVNULL)
    subprocess.run(["chvt", "1"], stdout=subprocess.DEVNULL, stderr=subprocess.DEVNULL)


# ── Counter reset (runs every second in background) ──────────────────────────
def reset_counter():
    global trigger_times

    if not _running:
        return  # stop spawning timers on shutdown

    with state_lock:
        if not locked and trigger_times:
            now = time.time()
            old_count = len(trigger_times)
            trigger_times = [t for t in trigger_times if now - t <= TRIGGER_WINDOW]
            if old_count > 0 and not trigger_times:
                print("45 seconden voorbij -> teller reset naar 0/3")

    threading.Timer(1, reset_counter).start()


# ── Stop show ────────────────────────────────────────────────────────────────
def stop_show():
    global locked, player, timer, trigger_times

    with state_lock:  # Controleert of videoproces nog draait
        if player and player.poll() is None:
            try:
                os.killpg(
                    os.getpgid(player.pid), signal.SIGTERM
                )  # Beëindigt volledige procesgroep
            except Exception:
                pass
            # Reset variabelen
        player = None
        timer = None
        trigger_times = []  # Lijst met tijdstippen van triggers
        locked = False
        last_trigger_time = 0.0

    led.off()
    screen_off()
    print("Video uit, scherm in slaapstand, teller reset naar 0/3")


# ── Start show ───────────────────────────────────────────────────────────────
def start_show():
    global locked, player, timer, trigger_times

    with state_lock:
        locked = True
        trigger_times = []

    screen_on()
    led.on()
    print("Signalen waargenomen: 3/3")
    print("3 geluidssignalen binnen 45 seconden -> video START")

    proc = subprocess.Popen(
        [
            "mpv",
            "--vo=drm",
            "--fs",
            "--no-border",
            "--really-quiet",
            "--no-terminal",
            "--no-config",
            "--cache=no",
            VIDEO,
        ],
        env=os.environ.copy(),
        stdout=subprocess.DEVNULL,
        stderr=subprocess.DEVNULL,
        start_new_session=True,  # own process group → os.killpg works correctly
    )

    with state_lock:
        player = proc

    t = threading.Timer(LOCK_TIME, stop_show)
    t.start()

    with state_lock:
        timer = t


# ── Sound trigger callback (runs in gpiozero thread) ─────────────────────────
def triggered():
    global trigger_times, last_trigger_time

    with state_lock:
        if locked:
            print("Trigger genegeerd: video speelt of lock actief")
            return

        now = time.time()

        # Cooldown: ignore signals within 10s of the last accepted trigger
        if now - last_trigger_time < TRIGGER_COOLDOWN:
            remaining = round(TRIGGER_COOLDOWN - (now - last_trigger_time))
            print(f"Trigger genegeerd: cooldown actief ({remaining}s resterend)")
            return

        last_trigger_time = now
        trigger_times = [t for t in trigger_times if now - t <= TRIGGER_WINDOW]
        trigger_times.append(now)
        count = min(len(trigger_times), TRIGGERS_NEEDED)

    print(f"Signalen waargenomen: {count}/3")

    if count >= TRIGGERS_NEEDED:
        start_show()


# ── Clean shutdown ────────────────────────────────────────────────────────────
def shutdown():
    global _running
    _running = False
    stop_show()
    sensor.close()
    led.close()
    subprocess.run(["setterm", "--cursor", "on"], stderr=subprocess.DEVNULL)
    print("Afgesloten.")


# ── Main ──────────────────────────────────────────────────────────────────────
screen_off()
sensor.when_activated = triggered
reset_counter()

print("Klaar. Wacht op 3 geluidssignalen binnen 45 seconden.")
print("Scherm staat in slaapstand zolang er geen video speelt.")

try:
    pause()
except KeyboardInterrupt:
    shutdown()
    sys.exit(0)

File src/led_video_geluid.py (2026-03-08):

from gpiozero import DigitalInputDevice, LED
from signal import pause
import subprocess
import os
import threading
import time
import signal

GPIO_SOUND = 17
GPIO_LED = 27

VIDEO = "/home/wokkel/kalmeer_video.mp4"
LOCK_TIME = 60  # 1 minuut projectie + lockout

# LM393 is meestal active-low → pull_up=True
sensor = DigitalInputDevice(GPIO_SOUND, pull_up=True)
led = LED(GPIO_LED)

locked = False
player = None
timer = None


def stop_show():
    """Stop video + LED en maak systeem weer klaar voor nieuwe trigger."""
    global locked, player, timer

    # Stop mpv als het nog draait
    if player and player.poll() is None:
        try:
            # We starten mpv in z'n eigen process group -> killpg stopt mpv netjes/hard
            os.killpg(player.pid, signal.SIGTERM)
        except Exception:
            pass

    player = None
    timer = None
    led.off()
    locked = False
    print(" 1 minuut voorbij -> video uit, LED uit, weer klaar")


def triggered():
    global locked, player, timer

    if locked:
        print("Trigger genegeerd (nog in lock)")
        return

    locked = True
    led.on()
    print(" Trigger -> video START (max 60s)")

    env = os.environ.copy()
    env["DISPLAY"] = ":0"

    # Start mpv fullscreen
    # start_new_session=True => eigen process group (handig om later te stoppen)
    player = subprocess.Popen(
        ["mpv", "--fs", "--no-border", "--really-quiet", "--no-terminal", VIDEO],
        env=env,
        stdout=subprocess.DEVNULL,
        stderr=subprocess.DEVNULL,
        start_new_session=True,
    )

    # Start 60s timer (nieuwe triggers verlengen dit niet)
    timer = threading.Timer(LOCK_TIME, stop_show)
    timer.start()


sensor.when_activated = triggered

print("Klaar. Wacht op geluid (GPIO17). LED op GPIO27.")
pause()

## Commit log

2026-03-08 code & BOM
2026-03-31 bom update
2026-05-07 CAD & afbeeldingen
    [control.prt, deksel.prt, handvaten.prt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]
2026-06-09 spelling, grammatica, afb, update
    [projector_steunv2.stl]
